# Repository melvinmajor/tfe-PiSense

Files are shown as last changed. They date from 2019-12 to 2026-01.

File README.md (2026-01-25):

> # PiSense
>
> *Originally: graduation work, 3rd Bachelor at EPHEC Louvain-la-Neuve*
>
> *Development pursued after the defense (project was well seen by the jury).*

PiSense logo

## The project

As part of a business request by Dreamnet SRL, an IoT system that tracks temperature, humidity and CO2 in a room is required to meet a future project to new needs.

Based on first feedback with Professor A. Dewulf (EPHEC), there is also interest in detecting Silicon Oxide from a client with a career.
This will allow the customer to prevent any risk related to the presence of Silicon Oxide at a rate too high.

> *The project is now functional under a [localhost web](localhost-web/) version with further options available on each sensors made compatible.*
>
> *If you want to use an external [web](web/) environment, please create your own API/database server with an online web environment.*
> *The Raspberry Pi code has a flag to fluently send collected data to an external environment.*

### Goal

Allow the optimization of the staff environment.
Studies have shown that a room with the right room temperature and good air quality can help focus and improve human health and productivity.

Multiple articles have been published, both from researchers and journalists based on the various studies carried out.
To cite only a few french sources, these two are explaining in summary the value of monitoring and optimizing the environmental data of the workplace:

* <https://www.francetvinfo.fr/replay-radio/c-est-mon-boulot/la-chaleur-a-des-effets-negatifs-sur-la-productivite_3486911.html>
* <https://www.forbes.fr/management/bonheur-au-travail-le-corps-ce-grand-oublie/>

In addition, it seems that in the professional environment, air pollution is an aggravating factor for respiratory pathologies.
An article correlate the facilitated spread of COVID-19 in this type of environment, was published by Le Soir and is available at the following address:

* <https://www.rtbf.be/info/societe/detail_le-coronavirus-pourrait-rester-plusieurs-heures-dans-l-air-a-cause-de-la-pollution-atmospherique?id=10464049>

In the case of the teacher's return, it would be a matter of warning of a possible danger in a risky work environment.

### Further research (after graduation defense)

After my graduation defense, I decided to pursue this project during my free time.
That's why I still make some commits 😉

By making further research, I learned that a desirable temperature is between 19 and 24°C (Canadian CSA Z412-17 Office Ergonomics suggest between 20 and 26°C).
The average humidity level is usually between 50 and 60% indoors even though between 40 and 70% there may not be high concerns.
Some articles and research published online explain this:

* <https://www.ccohs.ca/oshanswers/phys_agents/thermal_comfort.html>
* <http://ijesi.org/papers/Vol(4)3/Version-1/B043107014.pdf>
* <https://www.rubson.com/fr/a-propos-d-humidite/causes/niveau-parfait-humidite.html>

It seems that a bad humidity level can be linked to building and health aggravations.
For example:

* Humidity level below 20% can cause discomfort through dried eyes, mucous membranes and skin, skin and throat irritation.
It also causes static electricity build-up and negatively affect the operations of some office equipment such as printers and computers.
Apparently, it also has an impact on an easier drop in temperature which facilitates drying out the surrounding air.
* Humidity level above 70% may develop condensation on surfaces and within the interior of some equipment and building structures. If threatened, these areas can develop mould and fungi but also makes the area feel stuffy.
People with allergies may see their allergic reactions possibly worsening.

### Revival of the project (PiSense Lite, starting Q4 2024)

After taking a break from the project, I decided to work back on it with a lighter version, designed to be used in combination with a Home Assistant system.

If you are not aware, Home Assistant is an open source home automation system that puts local control and privacy first.
The project, from the Open Home Foundation, is stored on [GitHub](https://github.com/home-assistant) and their own [website](https://www.home-assistant.io/).

This revival, is stored under [PiSense-Lite with Home Assistant](PiSense-Lite%20with%20Home%20Assistant/) folder.

## License

This project is, by now on, protected under GNU General Public License v3.0 (see [LICENSE file](LICENSE)).
It's made available on GitHub for "documentation" purpose.

If you want to distribute it and/or use it commercially, please reach me before doing anything.
This condition is here since the very start of this repository project and is not meant to block the usage of my code.
It is only to be sure rights, patents and distribution are well respected based on me, the author.

## Built With and For

 

   

* [PyCharm Community Edition](https://www.jetbrains.com/pycharm/) - A great Python IDE

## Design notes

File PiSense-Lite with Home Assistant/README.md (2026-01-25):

> # PiSense Lite
>
> *Lite version of the project, with a focus on small energy consumption and compatibility with Home Assistant.*
> 
> Be aware this part of PiSense is purely for personal use. The code might need to be adapted for your needs.

PiSense logo

## The project

The project is to provide [Home Assistant](https://www.home-assistant.io/) with data from a sensor connected to a microcontroller.

In the case of this project, the microcontroller is a Raspberry Pi Pico W and the sensor selected is the Bosch BME680.
This sensor is interesting as it's a small and reliable one, giving measures of temperature, humidity, pressure and gas (which can be used to calculate VOC and AQI).
The Pico W is chosen as it has built-in WiFi capabilities, which will help us on requests between Home Assistant and the microcontroller.

The expected energy consumption should be around 50-60mA, making it quite energy efficient.

It is likely that other sensors will be added in the future, but the main priority is this first sensor.
Adapting the code for another microcontroller is possible (like an Arduino for example).

### Goal

* A fully working microcontroller with one or several sensors,
* An established communication between the microcontroller and Home Assistant via MQTT protocol,
* The integration of the sensors in a Home Assistant dashboard.

## Installation

For early adopters, feel free to follow this tutorial to connect your Raspberry Pi Pico to Arduino: <https://randomnerdtutorials.com/programming-raspberry-pi-pico-w-arduino-ide/>

In Arduino IDE, go into Preferences and enter the following URL into the "Additional Boards Manager URLs" field: <https://github.com/earlephilhower/arduino-pico/releases/download/global/package_rp2040_index.json>

You will also need to install couple modules in Arduino:

* Raspberry Pi Pico/RP2040
* WiFiManager
* PubSubClient

You will find in the Arduino file a bunch of variables at the beginning, feel free to adapt it to your needs:

```
// Replace with your WiFi credentials
const char* ssid = "YourSSID";
const char* password = "YourPassword";

// MQTT Broker
const char* mqtt_devicename = "PicoBME680"; // Name of the device in MQTT
const char* mqtt_server = "192.168.xxx.xxx"; // IP of the MQTT broker (Home Assistant)
const int mqtt_port = 1883; // Default port of Mosquitto MQTT is 1883. The secure one with SSL/TLS is 8883.
const char* mqtt_user = "mqttUserName";
const char* mqtt_password = "mqttPassword";
```
**Be sure you have MQTT installed on your Home Assistant as well as Mosquitto broker.**

In your Home Assistant, open the file editor and edit `configuration.yaml` to include the following:

```
mqtt:
  sensor:
    - name: "PiSense Temperature"
      state_topic: "home/pisense/bme680"
    - name: "PiSense Humidity"
      state_topic: "home/pisense/bme680"
    - name: "PiSense Pressure"
      state_topic: "home/pisense/bme680"
    - name: "PiSense Gas Resistance"
      state_topic: "home/pisense/bme680"
```

## License

This project is, by now on, protected under GNU General Public License v3.0 (see [LICENSE file](../LICENSE)).
It's made available on GitHub for "documentation" purpose.

If you want to distribute it and/or use it commercially, please reach me before doing anything.
This condition is here since the very start of this repository project and is not meant to block the usage of my code.
It is only to be sure rights, patents and distribution are well respected based on me, the author.

## Built With and For



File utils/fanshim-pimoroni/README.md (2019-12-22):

# Fan Shim for Raspberry Pi

> [Fanshim Python repository from Pimoroni](https://github.com/pimoroni/fanshim-python)

## Installing

* Stable library from PyPi: `sudo pip install fanshim`
* Latest/developement library from GitHub: `./fanshim-firstLaunch.sh` (fanshim pip will also be installed using this way)
  * If you have already installed it from GitHub and want to launch the app back: `./fanshim-launcher.sh`

As the code from Pimoroni install all the necessary things and create a service with our custom parameters implemented in the script, you won't need to relaunch the script at each reboot.

## Description

This part of the project will be used only when a fanshim must be set up on the device.

For example :

* Not really necessary for the Raspberry Pi Zero,
* Interesting for the Raspberry Pi 3 but not necessary,
* Highly recommended for the Raspberry Pi 4.

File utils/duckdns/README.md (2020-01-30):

# Duck DNS

Duck DNS is a free dynamic DNS hosted on AWS.
 
In fact, it helps to point a DNS (sub domains of [duckdns.org](https://www.duckdns.org/)) to an IP of your choice.

## Dynamic DNS service

It's a handy way to refer to a server/router with an easily rememberable name, where the servers IP address is likely to change.
When the router reconnects or ec2 server reboots, its IP address is set by the provider of that connection.
It means it may update at any time.

For the purpose of this project, the usage of Duck DNS is very handy as the Raspberry Pi is set on a DDNS environment.

## How to use

Simply run the script with the token set in argument: ´sudo ./duck.sh h3r3-1s-duckdns-t0k3n´.

It will return the token entered and then launch the process to connect to the Duck DNS service implemented.

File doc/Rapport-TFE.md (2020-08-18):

---
subtitle: Travail de fin d'études présenté en vue de l'obtention du diplôme de bachelier en Informatique et Systèmes orientation Technologie de l’informatique
date: Juin 2020
keywords: [TFE, graduation, work, PiSense, IoT, sensors, dev, report, TFE, graduation, rapport, EPHEC, 3TI]
header-left: Système modulable de prises de mesures environnementales avec affichage
footer-left: Rapport de TFE
footer-center: EPHEC 2019/2020
toc: true
toc-own-page: true
toc-title: Rapport de travail de fin d'études
---

# Système modulable de prises de mesures environnementales sur Raspberry Pi avec système d’affichage

> _**Titre du travail de fin d'études :**_ Système modulable de prises de mesures environnementales sur Raspberry Pi avec système d’affichage
>
> _**Nom temporaire prévu pour sa commercialisation :**_ PiSense
>
> _**Repository GitHub :**_ <https://github.com/melvinmajor/tfe-PiSense>
>
> _**Environnement web déployé :**_ <https://www.camposcasares.be>

**Préface**

Je souhaite tout d'abord remercier Dreamnet SRL et leurs contacts, car sans eux, ce projet n'aurait sans doute pas existé.
Leur soutien à été d'une grande aide malgré les circonstances atténuantes lié au COVID-19.

Je remercie également mon rapporteur de TFE, le professeur Arnaud Dewulf, pour les multiples échanges que nous avons eus et qui m'a permis de me conforter dans le choix de certains capteurs et de particularités à tenir en compte au niveau de l'aspect électronique de ce travail de fin d'études.

Je remercie également le client venant du professeur Arnaud Dewulf qui m'a orienté vers une réflexion poussée sur LoRaWAN et Zigbee.
Cela m'a permis de tenir en compte de possibles ouvertures en termes de moyen de communication.
De plus, il m'a permis de rediriger mes choix de capteurs afin de rendre ce travail le plus générique possible avec possibilité de personnalisation.
Malheureusement, au vu des circonstances mondiales rencontrées, nos échanges n'ont finalement pas donné de suite.

**Mesures liées au Coronavirus**

Suite aux mesures liées au Coronavirus, un impact non négligeable a eu lieu envers l'avancement du TFE.
En effet, il a été nécessaire de réadapter les échanges avec les deux clients et n'ai plus eu de retour concernant l'un d'eux.
De plus, avec les mesures gouvernementales prises et vivant seul, la distanciation sociale s'est faite ressentir de façon conséquente, impliquant une perte de motivation.
Quelques soucis de santé ont également été rencontrés durant cette période, faisant qu'un retard au niveau du développement de ce projet s'est installé ; retard dont j'ai mis un point d'honneur à récupérer.

En concertation avec le client principal, Dreamnet SRL, le développement s'est vu adapté.
L'optique principale étant d'avoir l'appareil de suivi environnemental opérationnel (pouvant communiquer avec une API et inscrire les données au sein d'une base de données), l'aspect web s'est vu altéré afin de montrer la possibilité de communication, sans pour autant avoir une gestion d'inscription et connexion utilisateur.

Vu les règles en vigueur lors du confinement, les colis jugés non prioritaires ont été retardés, occasionnant ainsi un retard considérable pour la réception du capteur SDS011 permettant la mesure de l'indice de qualité de l'air.

\pagebreak

## Introduction

Nous vivons dans un monde en perpétuelle évolution où la technologie prend une place d’importance majeure.
Les appareils connectés passent peu à peu d’une idée de conception à un produit se trouvant dans chaque foyer.
Malheureusement, il est rare de trouver à l’heure actuelle une solution tout-en-un permettant de suivre les informations environnementales directement depuis une interface web simple et efficace.

Dans un désir de suivre les informations environnementales de mon espace de vie, j'ai pris contact avec plusieurs entreprises, afin de voir le potentiel derrière ce projet.

Suite à des échanges avec plusieurs clients potentiels, ce travail de fin d’études s’est peu à peu dessiné.
Une entreprise mettait en avant l’intérêt d’obtenir des données liées à la température, l’humidité et la qualité de l’air afin d’améliorer la productivité de leurs employés.
Une autre mettait en avant la nécessité de suivre l’évolution de la présence d’un gaz spécifique dans un lieu donné, afin de prévenir d’un danger pouvant s’avérer mortel.

**En combinant les besoins et intérêts, les prémices de ce travail sont nées et de nouvelles questions venaient en tête :**

* _Serait-il possible d’imaginer une solution de petite taille et répondant aux demandes ?_
* _Est-ce que cette solution peut être générique afin d’être ouvert a tous ?_

De plus, avec les récents évènements liés au COVID-19, une réflexion approfondie a été réalisée concernant la mesure de la qualité de l’air suite à la publication de recherches spécifiques au coronavirus.

Vous découvrirez dans ce rapport la façon dont ce travail a été développé ainsi que certaines analyses réalisées.

### Analyse du projet

Un schéma d'analyse et un schéma du réseau physique ont été réalisés afin d'offrir une vue d'ensemble rapide sur la solution mise en place.

Vous les découvrirez aux pages suivantes.

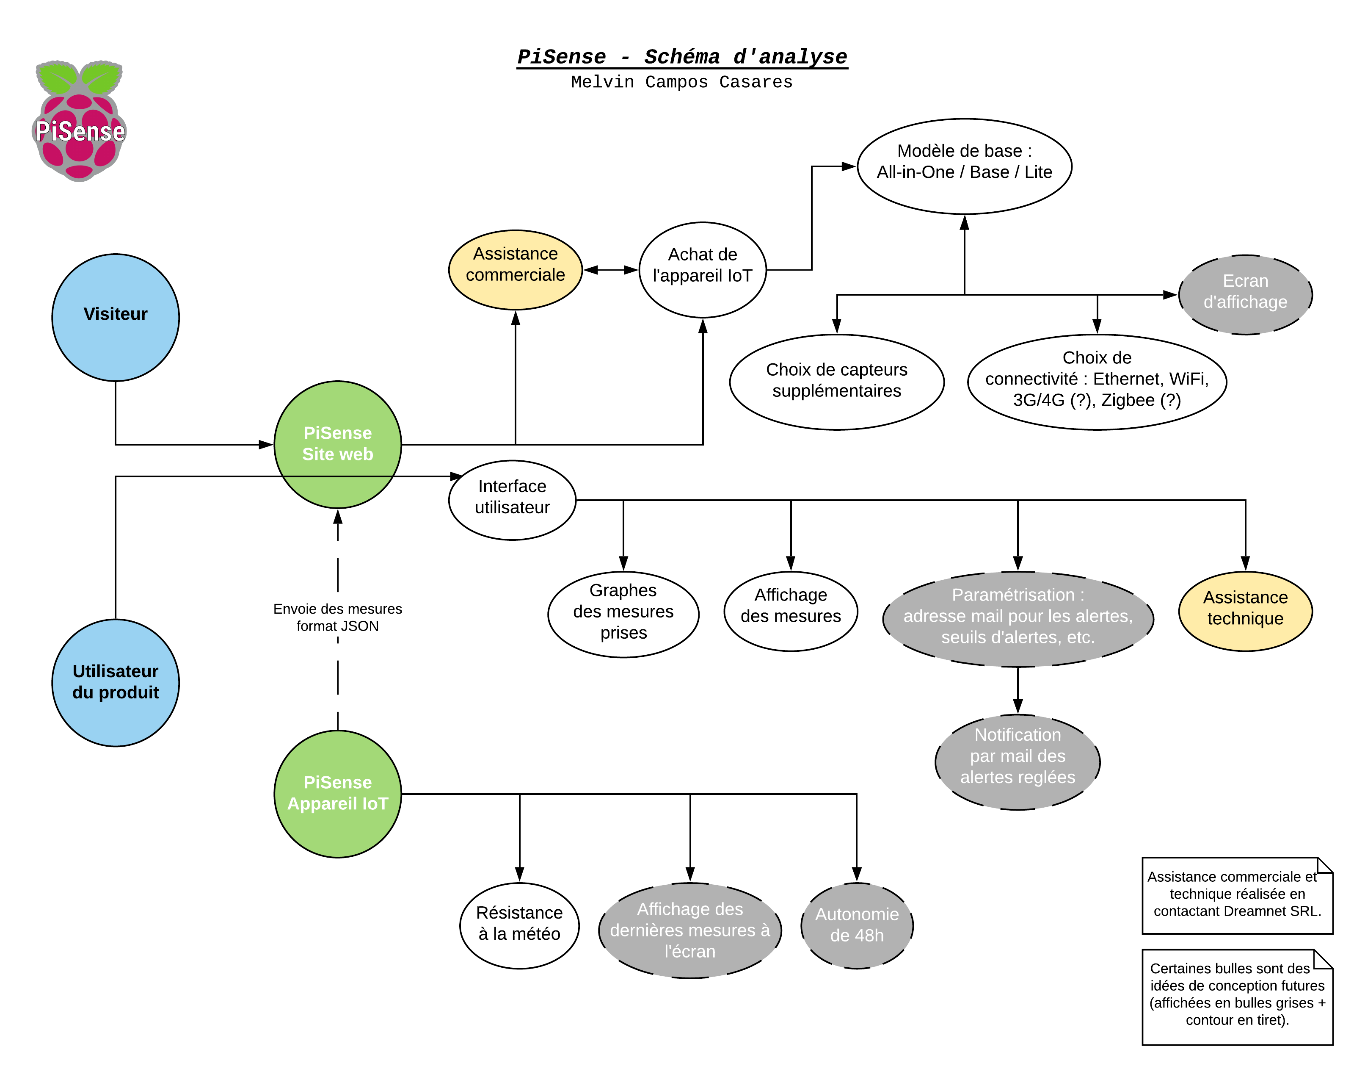
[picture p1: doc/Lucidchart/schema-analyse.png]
Schéma d'analyse du TFE


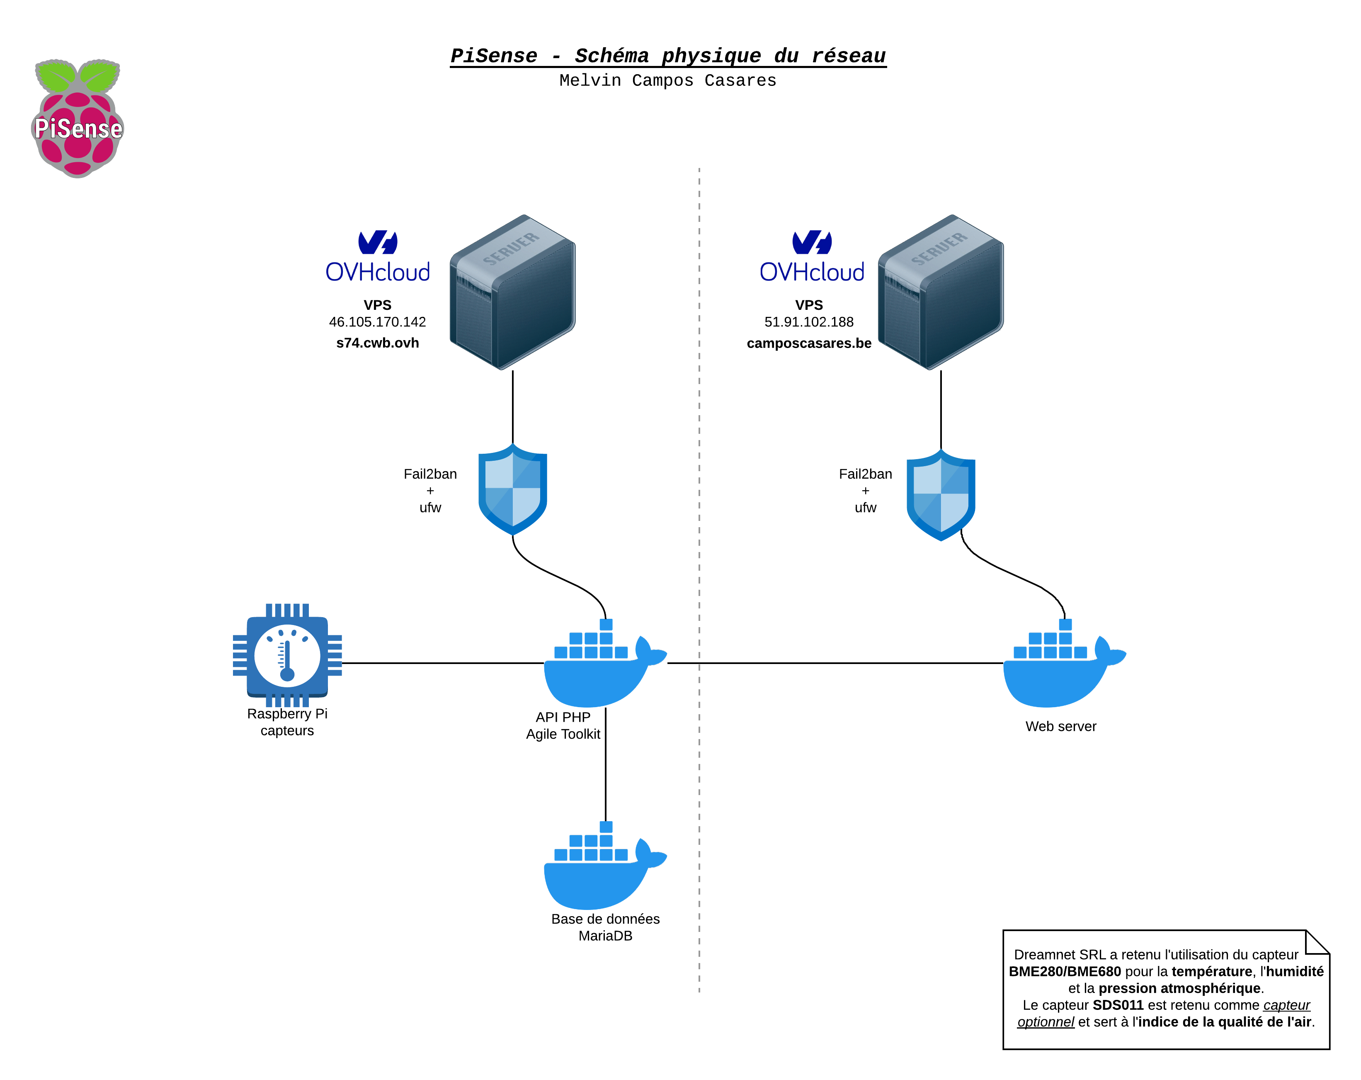
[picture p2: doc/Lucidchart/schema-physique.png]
Schéma physique du réseau


\pagebreak

## Informations générales de ce projet

### Contexte et présentation

Dans le cadre d’une requête professionnelle demandée par la société Dreamnet SRL, un système IoT permettant le suivi de la température, de l’humidité et du taux de CO2 au sein d’une pièce est requis afin de répondre à un projet futur faisant face à de nouveaux besoins.

Sur base de premiers retours avec le professeur A. Dewulf, un intérêt est également présent pour détecter de l’Oxyde de Silicium auprès d’un client disposant d’une carrière.
Cela permettra au client de prévenir de tous risques lié à une présence de l’Oxyde de Silicium à un taux trop élevé.

### But

Permettre l’optimisation de l’environnement du personnel.
Des études ont prouvé qu’une pièce à bonne température ambiante et avec une qualité d’air adéquate permet d’aider à la concentration et à améliorer l’état de santé ainsi que la productivité de l’être humain.

De multiples articles ont été publiés, tant venant de chercheurs que de journalistes se basant sur les différentes études réalisées.
Pour ne citer que quelques sources, en voici deux expliquant de façon synthétique l'intérêt de suivre les données environnementales du lieu de travail et de l'optimiser :

* <https://www.francetvinfo.fr/replay-radio/c-est-mon-boulot/la-chaleur-a-des-effets-negatifs-sur-la-productivite_3486911.html>
* <https://www.forbes.fr/management/bonheur-au-travail-le-corps-ce-grand-oublie/>

De plus, il semblerait que dans le milieu professionnel, la pollution atmosphérique est un facteur aggravant pour les pathologies respiratoires.
Un article allant dans ce sens, mettant en corrélation la propagation facilitée du COVID-19 dans ce type d'environnement, a été publié par Le Soir et est disponible à l'adresse suivante :

* <https://www.rtbf.be/info/societe/detail_le-coronavirus-pourrait-rester-plusieurs-heures-dans-l-air-a-cause-de-la-pollution-atmospherique?id=10464049>

Dans le cas des retours du professeur, il s’agirait de prévenir d’un éventuel danger dans un milieu de travail à risque.

### Besoins et contraintes

Il est demandé de mettre en place une solution IoT munie de capteurs « à la carte » ainsi que de différents moyens de communication au choix pour l’utilisateur final.

Ce choix permettra au client de définir ce dont il a besoin : Wi-Fi ou Ethernet.

Un moyen d’accès aisé aux informations est à mettre en place.
Le prix d’achat des composants pour créer l’appareil doit être le moins coûteux possible.
De ce fait, une analyse des différents composants disponibles sur le marché et de leur précision a été réalisée lors de l'élaboration du cahier de charges et de l'analyse technique afin de retenir uniquement les composants ayant un bon rapport précision/prix.

Concernant les nécessités du client disposant d’une carrière, une solution entièrement sans fil est à envisager.
L’utilisation d’une batterie d’une certaine capacité pourrait s’avérer pratique à moins que le client dispose d’une prise 220V non loin de la zone où il souhaite mettre en place l’appareil.

Malheureusement, au vu des problèmes rencontrés liés au confinement, les échanges avec le 2ème client n'ont plus eu lieu.

Étant donné que l’appareil pourrait être mis en extérieur, un boîtier étanche est à étudier.

#### Contraintes

* L’appareil IoT doit rester relativement petit (de taille « acceptable »),
* L’appareil IoT et les capteurs doivent être à un prix correct (volonté de ne pas dépasser les 500 € pour le kit complet avec tous les moyens de communication éventuellement intégrés),
* La possibilité à un développeur tiers d’accéder aux données de l’appareil via une API ou un environnement Cloud (non obligatoire, mais souhaité),
* La possibilité d’une solution entièrement sans fil,
* Résistance aux intempéries si l’appareil est mis en extérieur (résistance à la pluie).

\pagebreak

## Analyse de sécurité

En termes de sécurité, il va de soi que l'environnement web doit être sécurisé par un certificat SSL et une protection liée aux données des utilisateurs.
Dreamnet SRL conseille l'utilisation du certificat Let's Encrypt, étant un certificat gratuit et renouvelé de façon régulière.
L'augmentation de la sécurité par le biais de _Security Headers_ à implémenter sur la plateforme web est également une méthode intéressante à inclure.

> Concernant la sécurité mise en place sur la plateforme web, les éléments mis en place sont expliqués dans le point consacré à cet effet dans la section _Développement du projet > Site internet > Sécurité_.

Le moyen de communication de la Raspberry doit être le plus générique possible afin que même si une personne externe vient à récolter les informations, aucune information personnelle liée à l'utilisateur ne puisse être récupérée à son insu.

\pagebreak

## Développement du projet

### Méthodologie

Des réunions régulières ont été prévues avec Dreamnet SRL afin de s'assurer que la direction suivie soit la bonne.
La méthodologie suivie s'apparente donc aux méthodologies Agile et plus précisément Scrum.

Avec la période compliquée que nous avons subi, certaines contraintes ont été rencontrées, forçant de changer la manière de s'organiser ainsi que de la mise en place des réunions.

Le développement à débuté sur la partie IoT avec la Raspberry Pi pour ensuite laisser place au développement d'un site internet _"maquette"_.

### Raspberry Pi

Le développement a débuté avec la Raspberry Pi.
Plusieurs éléments ont été développés :

* Système de connexion à distance sécurisée par interface graphique via VNC Viewer (Raspberry Pi servant de serveur),
* Protection à la connexion par interface console par protocole SSH,
* Intégration d'un service permettant l'allongement de la durée de vie de la carte microSD,
* Développement d'un service permettant le refroidissement du processeur de la Raspberry Pi 4 via un ventilateur connecté sur le module GPIO intégré (la Raspberry Pi 4 est réputée pour avoir un processeur qui chauffe),
* Développement des différents capteurs.

Concernant les capteurs, tout a été développé avec le langage de programmation Python, l'intégration d'un service de logs avec rotation et suppression automatique de l'historique ancien de plus de 30 jours.

#### Capteurs

La réception des capteurs s'étant faite en plusieurs parties (3 fournisseurs différents pour 4 capteurs), 3 des 4 capteurs ont été reçus avant le confinement.
Le dernier capteur, le SDS011 permettant la mesure de l'indice de la qualité de l'air par le biais des normes PM2.5 et PM10, a été livré pratiquement 2 mois après avoir effectué la commande.

Voici les différents capteurs commandés et intégrés dans ce projet (ils sont tous fonctionnels) :

* _**Bosch BMP280**_ (modèle basé sur la librairie Adafruit) : prise de mesures de la température et humidité.
* _**Bosch BME280**_ (modèle basé sur la librairie Adafruit) : prise de mesures de la température, humidité et pression atmosphérique.
* _**Bosch BME680**_ (modèle de Pimoroni) : prise de mesures de la température, humidité, pression atmosphérique et calcul des taux de CO2 et composés organiques volatils totaux.
* _**Nova SDS011**_ : prise de mesures de l'air par le biais d'un laser et détection des particules fines d'après les normes de diamètre aérodynamique PM2.5 (< 2,5 µm) et PM10 (< 10 µm).

> À titre de comparaison, le diamètre aérodynamique d'un cheveu humain est de 50 à 70 µm.

En effet, mise à part le capteur BME680 en provenance du Royaume-Uni et commandé directement auprès de Pimoroni, les autres capteurs étaient tous en provenance de Chine.
Adafruit proposait de les commander directement de chez eux, mais le coût étant relativement conséquent, j'ai jugé bon de réduire les frais du TFE et commander les premiers capteurs dès la confirmation du sujet de TFE.

#### Journalisation d'événements, menu d'aide du script, etc.

En termes de dépassement, l'implémentation d'un système de rotation des fichiers "logs" propre à la Raspberry Pi avec suppression automatisée des fichiers datant de plus de 30 jours a été mise en place.
Toutes les informations jugées pertinentes _(données formatées en JSON et prêt pour l'envoi vers l'API, réponse de réussite ou d'erreur lors de l'envoi vers l'API, etc.)_ sont stockées dans un fichier de journalisation d'événements ayant la dénomination suivante : `NomDuCapteur.log.Année-Mois-Jour` _(exemple : bme680.log.2020-06-01)_.

De plus, un menu d'aide a été intégré pour chacun des capteurs permettant de démarrer le script avec la déclaration personnalisée de l'URL du serveur API, du temps entre chaque prise de mesures et la version du script présent sur l'appareil.

_**Voici le menu d'aide du capteur BME280 :**_

`mcc@RasbperryPi4: $ sudo python3 bme280/bme280sensor.py --help`

```fish
usage: PiSense BME280 [-h] [-u URL] [-t TIME] [-v]

BME280 module sensor of PiSense

optional arguments:
  -h, --help            show this help message and exit
  -u URL, --url URL     URL of the API
  -t TIME, --time TIME  Time, in seconds, between each record taken
  -v, --version         PiSense BME280 program version
```

#### Photos de l'appareil

Voici, aux pages suivantes, des photos de la Raspberry Pi 4 dans un boitier en aluminium, sous différents angles et avec les capteurs branché.

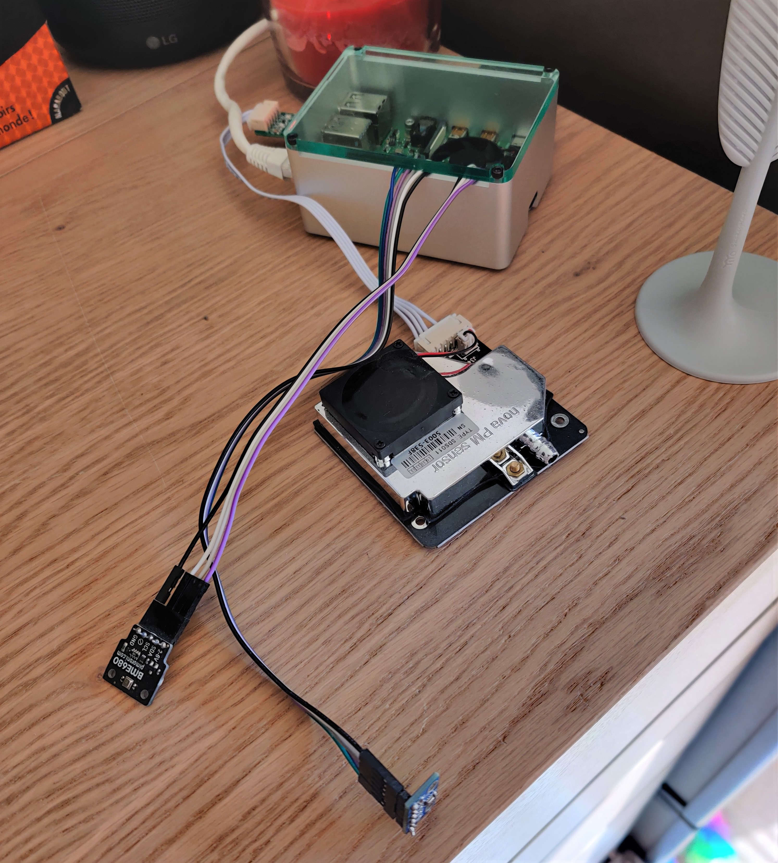
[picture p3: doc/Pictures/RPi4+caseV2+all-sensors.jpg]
Raspberry Pi 4 avec les capteurs BME280, BME680 et SDS011 branché


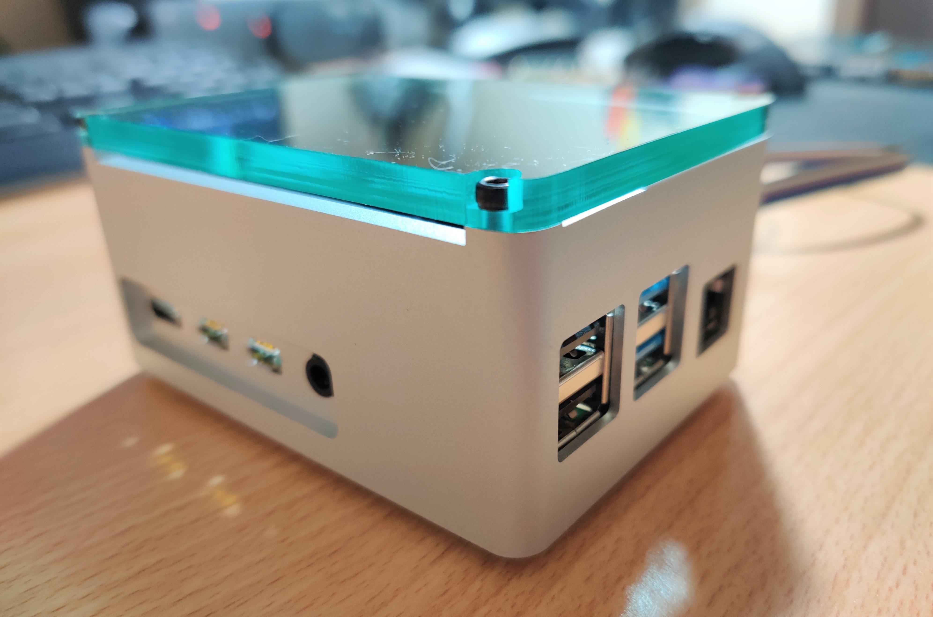
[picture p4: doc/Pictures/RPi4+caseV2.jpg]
Raspberry Pi 4 avec un boitier en aluminium


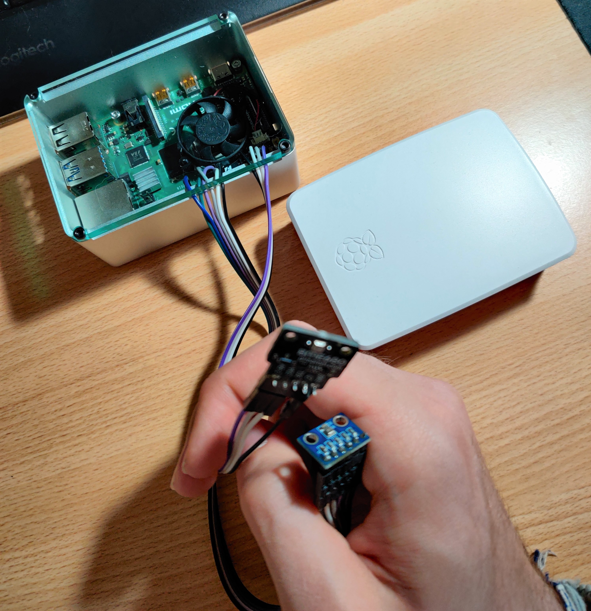
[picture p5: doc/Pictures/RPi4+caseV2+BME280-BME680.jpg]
Raspberry Pi 4, vu de haut, avec les capteurs BME280 et BME680 branché


\pagebreak

### Site internet

Au niveau du site internet, il était originellement prévu de travailler sur une plateforme avec le framework React.JS.
J'ai rapidement pu remarquer les limites de cet environnement de développement par rapport aux besoins de ce projet et aie donc entrepris de changer d'environnement de travail.

#### Sécurité

##### Certificat Let's Encrypt (HTTPS)

Concernant la sécurité, le certificat HTTPS a été mis en place.
Let's Encrypt a été utilisé, avec `certbot` afin d'automatiser son renouvellement.

Let's Encrypt est une autorité de certification gratuite, automatisée et ouverte, exploitée pour le bénéfice du public. C'est un service fourni par l’Internet Security Research Group (ISRG).
Leur optique étant de créer un Web plus sûr et respectueux de la vie privée, ils offrent les certificats numériques pour activer le protocole de sécurité HTTPS (SSL/TLS) pour les sites web, gratuitement.

On peut remarquer sa mise en place sur le serveur web via le rapport de sécurité réalisé auprès de Qualys :

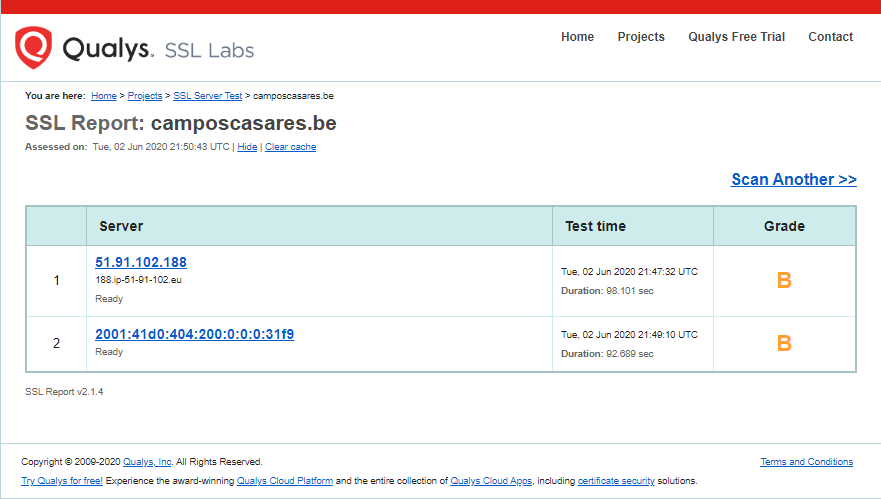
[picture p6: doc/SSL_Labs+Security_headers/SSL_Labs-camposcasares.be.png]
Rapport de sécurité SSL


##### En-tête de sécurité

De plus, des security headers ont été mis en place afin d'assurer une protection supplémentaire de la plateforme web.
En protégeant les en-têtes de sécurité HTTP/HTTPS, les attaques et les vulnérabilités de sécurité sont atténuées.

Les en-têtes de sécurité HTTP sont la réponse au navigateur, lorsqu'il effectue une requête.
Certains de ces en-têtes contiennent de méta data de contenu tels que le code de statut, la méthode utilisée par la requête (GET/POST...), l'adresse URL de la requête, le contenu d'encodage et le contrôle de la cache.
Cela définit donc notamment comment le navigateur web doit réagir en affichant le contenu de la page web demandée.

Voici le rapport d'analyse des en-têtes de sécurité de la plateforme :

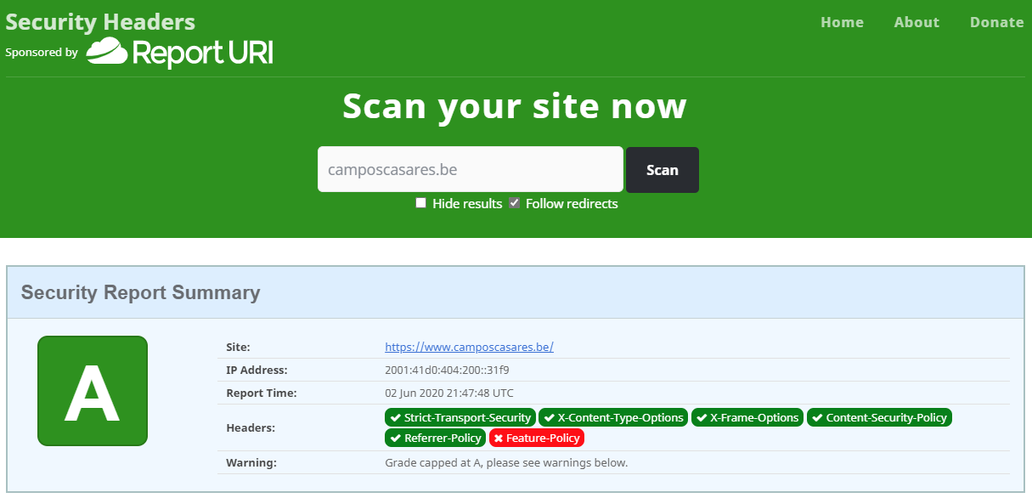
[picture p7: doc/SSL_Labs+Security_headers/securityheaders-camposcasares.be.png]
Rapport des security headers


###### Content Security Policy (CSP)

Cette stratégie permet de prévenir des attaques, telles que le script de site croisé (XSS) et d'autres attaques d'injection de code en définissant les sources de contenu approuvées et en permettant au navigateur de les charger.

Dans la configuration du serveur NGINX, cela concerne : `Content-Security-Policy`.

###### Filtre de script de site croisé (X XSS-Protection)

L’en-tête est conçu pour activer le filtre de script de site croisé (XSS) intégré dans les navigateurs web modernes.
Il est généralement activé par défaut, mais le spécifier est toujours préférable.

Dans la configuration du serveur NGINX, cela concerne : `add_header X-XSS-Protection "1; mode=block" always;`

###### HTTP Transport de sécurité stricte (HSTS)

Il permet de restreindre les navigateurs web pour accéder au serveur web uniquement via le protocole de sécurité HTTPS.
Cela garantit que la connexion ne peut pas être établie via une connexion HTTP non sécurisée et ainsi prévenir de susceptibles attaques.

Dans la configuration du serveur NGINX, cela concerne : `Strict-Transport-Security`.

###### Protection de clics

En utilisant `X-Frame-Options`, une protection contre les clics est établie et les iframes ne peuvent pas être chargées sur le site web.

###### Blocage de détection de réponse éloignée

`X-Content-Type-Options` permet de prévenir la détection de réponse éloignée déclarée.
Cela permet de réduire le risque de téléchargements de type "drive-by" (= téléchargement de contenu autorisé sans tenir compte des conséquences (exécutable contrefait, application non reconnue/signée...)) et ainsi traiter le contenu de la bonne façon.

###### Référence de politique HTTP

`Referrer-Policy` contrôle la quantité d'informations de référence, qui doit être incluse dans les demandes.

Sur le serveur NGINX, `strict-origin-when-cross-origin` a été défini.
Concrètement, l'origine est envoyée (le chemin et la chaîne de requête) lors de l'exécution d'une demande de même origine.
L'origine n'est envoyée que lorsque le niveau de sécurité du protocole reste le même lors de l'exécution d'une demande d'origine croisée (HTTPS → HTTPS), et n'envoie aucun en-tête à un système moins sécurisé (HTTPS → HTTP).

#### Changement du serveur web vers Python Flask

Fin mars, j'ai entrepris la conversion complète du site internet pour travailler sur le framework Flask prévu pour Python.

Afin d'améliorer au maximum le rendement de ce framework, le modèle MVT a été suivi (ce modèle est expliqué à la suite dans un point dédié).
L'avantage de Python Flask est son intégration plus aisée de l'API ainsi que de la base de données.

Afin de comprendre au mieux l'utilisation de Flask, j'ai suivi la formation en ligne "Concevez un site avec Flask" sur OpenClassrooms.

##### Modèle MVT

Concernant la plateforme web, le modèle MVT (Modèle - Vue - Template) est suivi.

* Le modèle est la structure de l'objet dans la base de données.
  Concrètement, il est représenté par le fichier `models.py`.
* La vue décide du contenu qui sera affiché sur une page ; c'est elle qui génère le contenu à renvoyer aux requêtes adressées.
  Concrètement, il est représenté par le fichier `views.py`.
* Le template est un fichier HTML recevant des objets Python et lié à une vue.
  Concrètement, il est représenté par le dossier `templates` et tout fichier présent dans ce dernier.

##### API

Python Flask permet la mise en place d'une API (Application Programming Interface).
La documentation fournie sur le site internet officiel de Flask est relativement complète.

Dans le cadre de ce projet, j'ai suivi la formation en ligne "Adoptez les API REST pour vos projets web" sur OpenClassrooms.
Cette formation m'a permis de mieux visualiser les concepts théoriques derrière les API et ainsi orienter la programmation de ce dernier.

###### Changement de l'API vers PHP Agile Toolkit framework

Malheureusement, en avançant dans la construction de l'API, j'ai été face à quelques problèmes de compréhension afin de mettre en place correctement les éléments nécessaires pour finaliser le site web avec Python Flask.
Arrivé début mai, j'ai dès lors pris contact avec Dreamnet SRL afin de changer un peu les attentes du projet et convenir d'un arrangement.

Une partie du cahier de charges original concernant le site web est donc reléguée à un développement ultérieur, la partie échange de communication entre la Raspberry Pi et le site web étant la priorité.

Le langage final choisi est PHP avec Agile Toolkit et la conversion entre ce qui a déjà été réalisé sous Python Flask et le nouvel environnement sous PHP n'a pas occasionné un retard plus conséquent que celui déjà préexistant.

#### Impression d'écran de l'interface web

Voici l'interface utilisateur disponible en ligne.
Il présente de façon claire et détaillée les mesures prises des 30 derniers jours.
L'utilisateur peut parcourir avec sa souris les mesures prises à chaque instant s'il souhaite plus de détails.

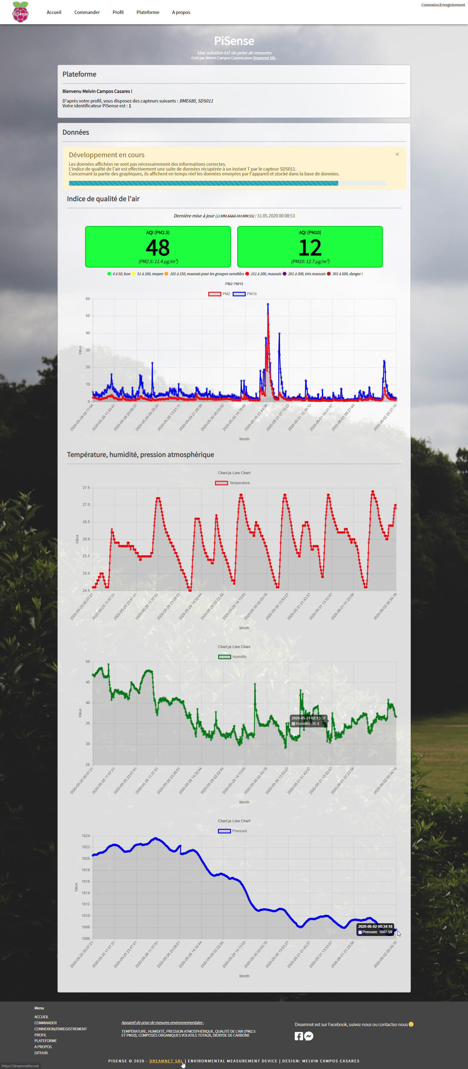
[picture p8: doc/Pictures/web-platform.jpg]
Impression d'écran de l'interface web avec les graphes


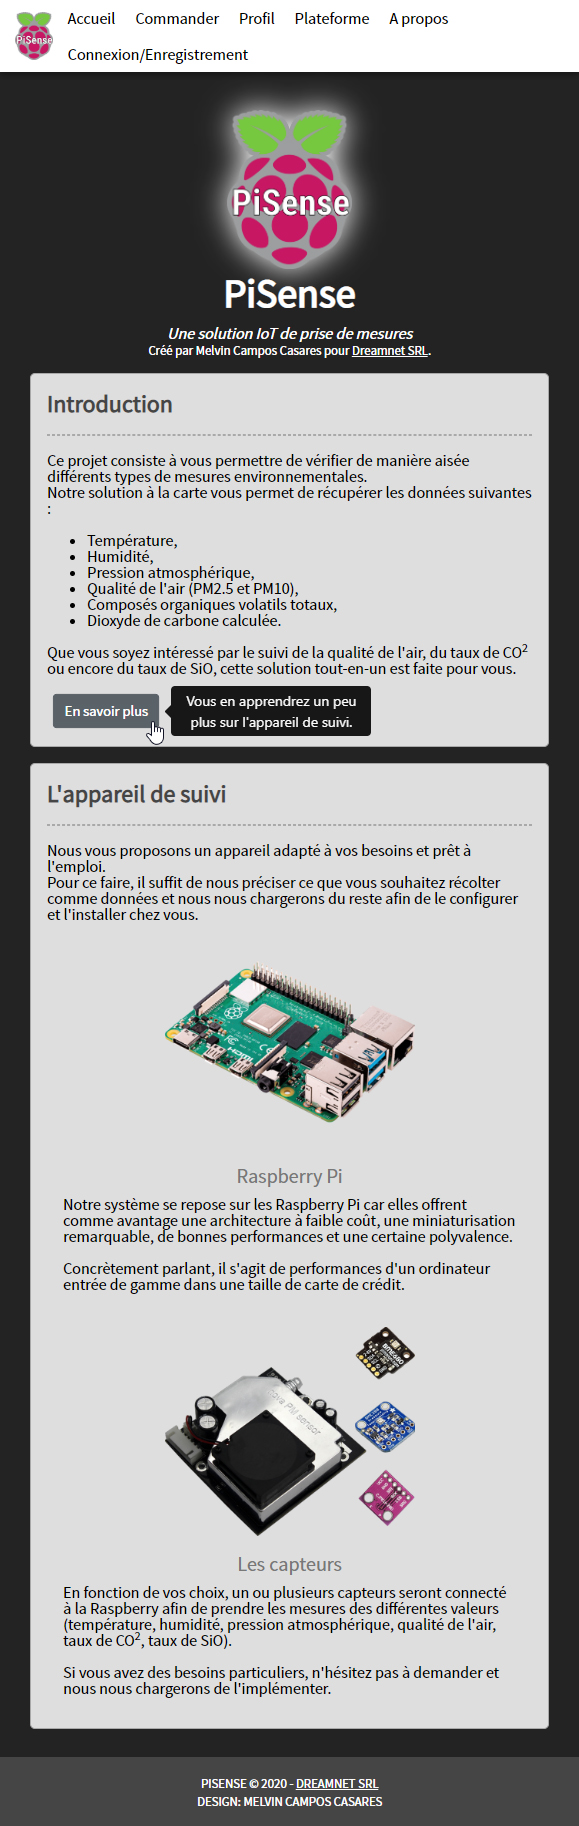
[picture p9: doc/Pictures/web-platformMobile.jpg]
Impression d'écran de la page d'accueil sur un appareil mobile


\pagebreak

### Base de données

Lors du choix de technologies, il était décidé de partir sur MariaDB, car jugé plus intéressant en termes de fonctionnalités, stabilité et de la licence Open SQL Server en comparaison de MySQL.
Au vu de certaines incompatibilités rencontrées avec MariaDB lors de l'implémentation de l'environnement web sous Python Flask, SQLite a été le choix de prototypage retenu, mais MariaDB est bel et bien la solution retenue et déployée grâce au changement de structure utilisée lors de la mise en place de l'API.

Concrètement parlant, la base de données comporte 2 tables :

* _**User**_ :
  Elle contient toutes les informations liées à l'utilisateur. Nous y trouverons son nom et prénom, adresse e-mail, mot de passe (qui sera protégé), date d'inscription et s'il est en possession d'un appareil de suivi ainsi que de quel(s) capteur(s).
* _**Box**_ :
  Elle contient les informations liées à la Raspberry Pi et les capteurs. Nous y trouverons les différentes informations environnementales tout comme l'ID de l'appareil ainsi que l'horodatage de la prise de mesure.

> À noter que la présence des données des capteurs dans la table Box est un choix réfléchi et à pour but de simplifier les requêtes réalisées auprès de l'API et la base de données afin de rendre l'inscription et la récupération des informations plus rapide et efficace.

Avec les changements occasionnés au niveau du site internet ainsi que les réadaptations nécessaires au niveau du développement dû aux circonstances liées au COVID-19, seule la table Box sera utilisée même si la table User est fonctionnelle et utilisable pour le développement ultérieur par le client.

\pagebreak

## Problèmes rencontrés

### Confinement (COVID-19)

Avec cette période exceptionnelle que nous rencontrons cette année via la présence de mesures strictes de confinement afin de contrer le coronavirus, cela a eu un impact non négligeable sur l'avancée de ce TFE.

En effet, avec le stage en télétravail, les quelques semaines de stage suspendus qui sont à rattraper et la distanciation sociale, j'ai dû réadapter à plusieurs reprises mon planning de travail.
Vivant seul, j'ai ressenti la distanciation sociale de façon conséquente et ait perdu mon rythme de travail, entre autres, dû à un manque de motivation lié à la solitude ressentie et quelques soucis de santé rencontrée.

De plus, je n'ai eu que peu d'échanges avec les clients concernant mon TFE faisant que le développement n'a pu être avancé principalement que sur base des notes prises lors d'entrevues avant les mesures prises par le gouvernement.
Dreamnet SRL a répondu présent lors de nos échanges par mail malgré une réponse parfois lente dû à une surcharge de travail lié aux urgences clientèle, mais je n'ai eu aucune nouvelle du second client.

Au vu des règles en vigueur lors du confinement, les colis jugés non prioritaires se sont vu être retardés, occasionnant ainsi un retard considérable pour la réception du capteur SDS011 permettant la mesure de l'indice de qualité de l'air.

### Incompatibilité entre les technologies choisies

Au début du projet, sur base des demandes du client et d'une analyse amenant à l'élaboration d'un cahier de charges, certains choix de technologies m'avaient semblé évidents.
C'était sans compter la complexité de mise en place du framework React.JS au niveau de l'environnement web.

Une première réadaptation des choix technologiques a été faite en quittant le framework React.JS au profit du framework Flask.

Malheureusement, des soucis de connexion entre Python Flask et la base de données MariaDB se sont présentés très rapidement, nécessitant le changement vers SQLite qui lui, ne pose aucun problème d'interaction par le biais du module SQLAlchemy utilisé par Flask pour interagir avec une base de données.

Au vu de la réadaptation du développement de l'API, SQLite s'est avéré être efficace lors du prototypage, mais MariaDB a finalement été mis en place avec l'API PHP sous framework Agile Toolkit, respectant ainsi l'intérêt premier au niveau du choix technologique de la base de données.

\pagebreak

## Piste d'amélioration

### Mise en place d'un système de connexion utilisateur

Comme prévu pour la version commercialisable de ce sujet de TFE, un environnement permettant aux utilisateurs de s'inscrire et avoir accès aux informations spécifiques de leur compte pourrait être mis en place.

Cela permettrait ainsi de profiter d'un environnement unique et facile d'utilisation pour l'utilisateur sans la nécessité de dépendre d'un site internet unique à chacun.

### Application permettant la configuration rapide de la Raspberry Pi

Une application mobile se connectant à la Raspberry Pi pourrait être développée afin de faciliter la première mise en route.
De cette manière, l'utilisateur n'aurait plus à devoir fournir les informations de connexion à son réseau sans fil et pourrait de lui-même configurer et reconfigurer à souhait son appareil de suivi de mesures.

### Système de commande complète en ligne

À l'heure actuelle, la prise en charge des commandes se réalise exclusivement que par prise de contact via échange mail et/ou par appel téléphonique avec Dreamnet SRL.
Un formulaire pourrait être mis en place avec système de processus de paiement par carte bancaire afin d'automatiser la commande.

### Utilisation de la modélisation 3D d'un boitier adapté au projet

Une modélisation 3D d'un boitier permettant l'installation d'une Raspberry Pi avec le capteur Nova SDS011 ainsi qu'un second capteur au choix parmi BMP280/BME280/BME680 a été réalisé.

Théoriquement, les mesures devraient être correctes et la modélisation utilisable pour sa production.
Néanmoins, il serait intéressant de vérifier cela en pratique, réaliser les modifications éventuelles à apporter et ainsi profiter d'une solution entièrement personnalisée pour sa commercialisation.

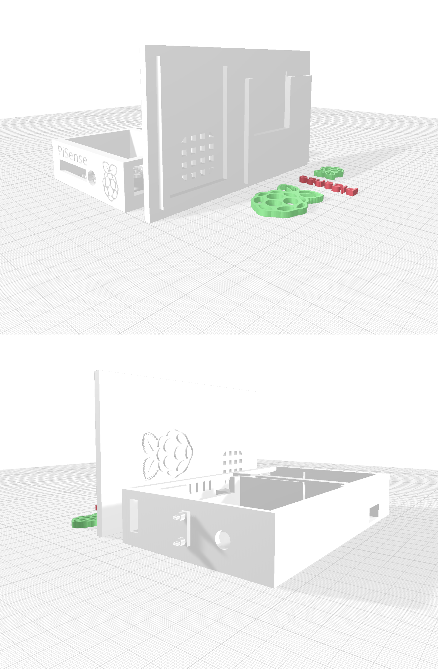
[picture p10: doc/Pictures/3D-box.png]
Modélisation 3D d'un boitier prévu pour l'appareil de prises de mesures envrionnementales


\pagebreak

## Conclusion

Ce sujet de TFE m'a énormément appris.
J'ai eu l'occasion de pouvoir m'améliorer dans le langage de programmation Python, mieux comprendre certaines utilisations au niveau des modules et librairies, mais également de comprendre les différences entre Python 2.x et Python 3.x.
En effet, parmi les différents capteurs utilisés dans le cadre de ce projet, le capteur de détection de fines particules ne disposant pas de librairies spécifique et ayant une communication en série, il ne m'était pas possible de travailler avec ce capteur en Python 3.x tout comme les autres capteurs.

Certains choix technologiques décidés au départ lors de l'écriture du cahier de charges se sont avérés rendre le travail complexe et lors de l'avancement du développement, je me suis rapidement rendu compte des incompatibilités sur certains aspects.
Cela a occasionné un retard qui était nécessaire à rattraper pour mener à bien ce projet.

La situation particulière que nous avons vécue en ce début d'année 2020, avec la présence du confinement lié à la pandémie du COVID-19, a rendu difficile l'avancement du travail de fin d'études comme expliqué précédemment dans les problèmes rencontrés.

Le cahier de charges a dû être revu avec le client afin de rester réalisable et s'assurer des bons choix technologiques.
La communication avec les clients s'est avérée être plus difficile durant cette période de pandémie, mais des arrangements ont pu être trouvés afin de pouvoir discuter du projet sans être livré intégralement à soi.

En termes de développement, la partie concernant l'appareil de suivi environnemental est intégralement fonctionnelle.
L'API et la base de données sont également fonctionnels et l'appareil de suivi interagit sans problème avec.
L'environnement web présente les possibilités d'interaction utilisateur envisageable (visibilité des graphes), mais aucune gestion de notification sur base d'alertes personnalisées ou de création de compte utilisateur/connexion utilisateur n'est gérée malgré que la structure soit existante au niveau de l'API et de la base de données, comme convenu avec le client.

\pagebreak

## Bibliographie

_**Partie IoT/Raspberry Pi :**_

* _Raspberry Pi 4 GPIO Pinout_, par Eduardo Pecina, <https://maker.pro/raspberry-pi/tutorial/raspberry-pi-4-gpio-pinout>
* _Adafruit BME280 Humidity + Barometric Pressure + Temperature Sensor Breakout_, <https://learn.adafruit.com/adafruit-bme280-humidity-barometric-pressure-temperature-sensor-breakout>
* _Adafruit BMP280 library_, repository GitHub appartenant à Adafruit, <https://github.com/adafruit/Adafruit_BMP280_Library>
* _Adafruit BME280 library_, repository GitHub appartenant à Adafruit, <https://github.com/adafruit/Adafruit_BME280_Library>
* _Pimoroni BME680 library_, repository GitHub appartenant à Pimoroni, <https://github.com/pimoroni/bme680>
* _Getting Started with BME680 Breakout_, Pimoroni, <https://learn.pimoroni.com/tutorial/sandyj/getting-started-with-bme680-breakout>
* _SDS011 dust sensor reading_, code publié sur GitHub appartenant à kadamski, <https://gist.github.com/kadamski/92653913a53baf9dd1a8>
* _Fanshim Python_, repository GitHub appartenant à Pimoroni, <https://github.com/pimoroni/fanshim-python>
* _Apprenez à programmer en Python_, Openclassrooms, <https://openclassrooms.com/fr/courses/235344-apprenez-a-programmer-en-python>
* _Getting Started with Fan SHIM_, PIMORONI, <https://learn.pimoroni.com/tutorial/sandyj/getting-started-with-fan-shim>
* _Requests : HTTP for Humans_, <https://requests.readthedocs.io/en/master/>
* _Python’s Requests Library (Guide)_, publié le 23/01/2019, <https://realpython.com/python-requests/>
* _Documentation Python v3.7_, Python Software Foundation, <https://docs.python.org/3.7/>
* _Python 3 - JSON encoder and decoder_, Python Software Foundation, <https://docs.python.org/3/library/json.html>

_**Partie web :**_

* _Documentation Python v3.7_, Python Software Foundation, <https://docs.python.org/3.7/>
* _Flask Documentation_, <https://flask.palletsprojects.com/en/1.1.x/>
* _Flask API documentation_, <https://flask.palletsprojects.com/en/1.1.x/api/>
* _Documentation Bootstrap_, Bootstrap, <https://getbootstrap.com/docs/4.5/getting-started/introduction/>
* _Code Snipetts | CSS-Tricks_, CSS-tricks, <https://css-tricks.com/snippets/>
* _CSS Almanac | CSS-Tricks_, CSS-tricks, <https://css-tricks.com/almanac/>
* _ChartJS_, ChartJS, <https://www.chartjs.org/>
* _Agile Toolkit_, <https://agiletoolkit.org/>
* _Agile UI Documentation_, <https://agile-ui.readthedocs.io/en/latest/>

_**Partie Base de données :**_

* _Documentation MariaDB_, <https://mariadb.com/kb/en/documentation/>
* _Documentation SQLite_, <https://sqlite.org/docs.html>

_**Partie API :**_

* _Adoptez les API REST pour vos projets web_, Openclassrooms, <https://openclassrooms.com/fr/courses/6573181-adoptez-les-api-rest-pour-vos-projets-web>
* _ChartJS_, ChartJS, <https://www.chartjs.org/>
* _Agile Toolkit_, <https://agiletoolkit.org/>
* _Agile UI Documentation_, <https://agile-ui.readthedocs.io/en/latest/>
* _ATK Data - Data Access Framework for high-latency databases (Cloud SQL/NoSQL)_, repoistory GitHub appartenant à ATK4, <https://github.com/atk4/data/>

_**Autres sources :**_

* _docker-compose_, Docker, <https://docs.docker.com/compose/>
* _Use volumes_, Docker, <https://docs.docker.com/storage/volumes/>
* _Content Security Policy (CSP) Quick Reference Guide_, Foundeo Inc., <https://content-security-policy.com/>
* _La chaleur a des effets négatifs sur la productivité_, France TV Info, <https://www.francetvinfo.fr/replay-radio/c-est-mon-boulot/la-chaleur-a-des-effets-negatifs-sur-la-productivite_3486911.html>
* _Le bonheur au travail : le corps, ce grand oublié_, Forbes, <https://www.forbes.fr/management/bonheur-au-travail-le-corps-ce-grand-oublie/>
* _Pollution et propagation fulgurante du coronavirus, les particules fines montrées du doigt_, Le Soir, <https://www.rtbf.be/info/societe/detail_le-coronavirus-pourrait-rester-plusieurs-heures-dans-l-air-a-cause-de-la-pollution-atmospherique?id=10464049>

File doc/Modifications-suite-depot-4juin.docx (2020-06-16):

TFE - Résumé des modifications

- Gestion des erreurs 403 (accès refusé) et 405 (méthode/requête non autorisée ou n’aboutissant pas).
- Ajout d’une balise permettant la personnalisation de la couleur de la barre d’adresse dans les navigateurs compatibles (exemple : Google Chrome Mobile).
- Correction du message d’erreur à la connexion et correction de la redirection à la connexion.
- Ajout de balises « meta tags » : description, auteur, mots clés, robots (indexation et/ou suivi des pages web ou non).
- Écriture d’un mode d’emploi concernant la connexion des différents capteurs sur la Raspberry Pi (déjà présent dans le Wiki du repository GitHub).
- Préchargement HTTP Strict Transport Security (HSTS) : permet de s’assurer que les navigateurs gardent en mémoire le site internet comme étant certifié HTTPS.
- Amélioration des protocoles SSL et changement de grade d’après le rapport généré par Qualys SSL Labs : passage du grade B au grade A+.
- Test de rapidité effectué auprès de Testmysite.io (Netlify Speedtest) concernant le site internet : résultat de 86/100 obtenu, TTFB (Time To First Byte) pose problème comme la plupart des sites internet.

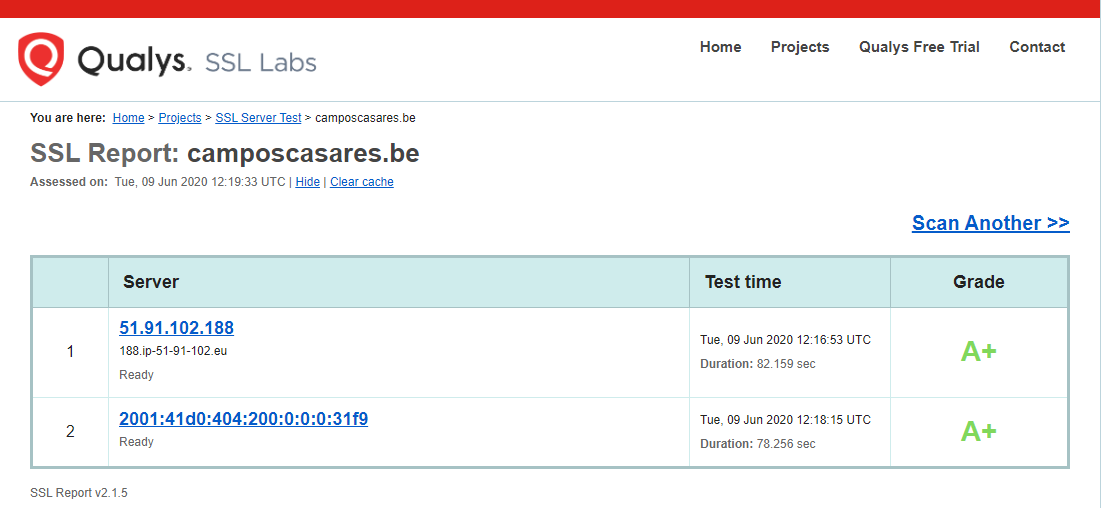
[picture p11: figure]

- Ajout du header Feature-Policy permettant la (dés)activation de certaines options des navigateurs et API pour une meilleure sécurité et respect de la vie privée.

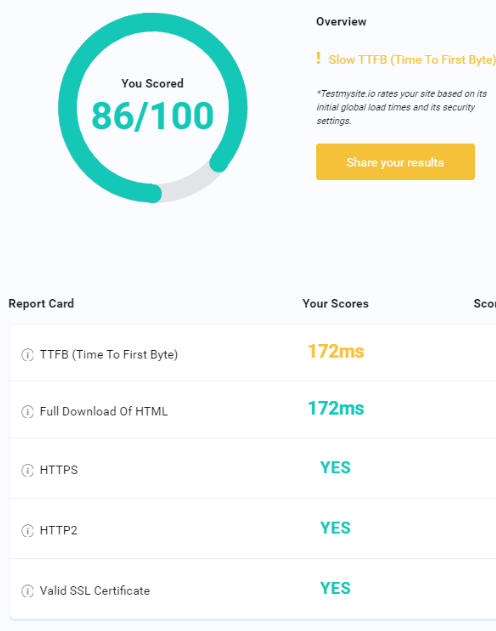
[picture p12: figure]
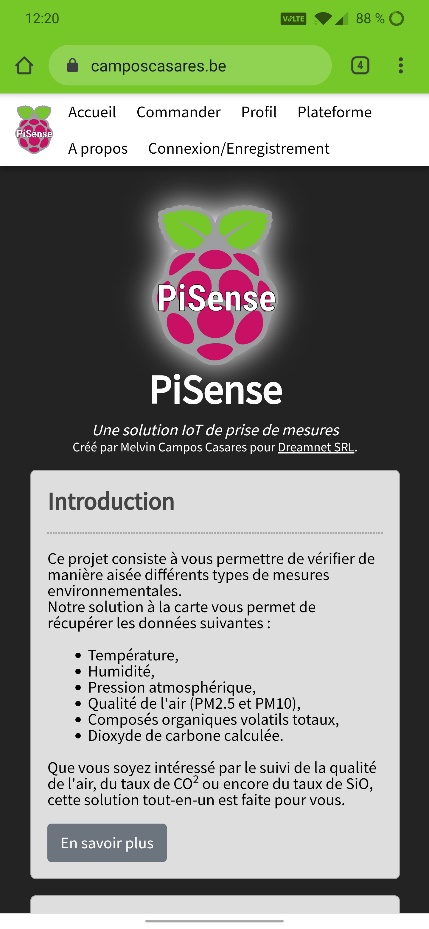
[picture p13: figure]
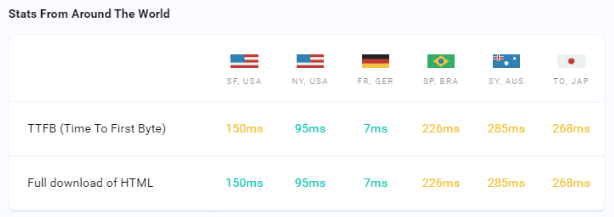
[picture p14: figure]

TFE : Système modulable de prises de mesures environnementales avec affichage Résumé des modifications suite au dépôt du 4 Juin 2020

Melvin Campos Casares EPHEC – 2019/2020 Rapporteur : Arnaud Dewulf Juin 2020

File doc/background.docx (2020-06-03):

3TL2

ECOLE PRATIQUE DES HAUTES ETUDES COMMERCIALES
EPHEC
Avenue du Ciseau, 15
1348 Louvain-la-Neuve

Année académique 2019-2020

EPHEC

Rapporteur : Arnaud Dewulf

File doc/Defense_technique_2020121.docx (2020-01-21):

Plan de présentation :

- Présentation du sujet de TFE
  - Titre : Plateforme web visant à afficher les mesures prises par une Raspberry Pi avec différents capteurs environnementaux et de gaz.
  - Quoi : Plateforme web reliée à un appareil de prise de mesures qui récupère différentes valeurs. Cet appareil est proposé à la carte (base générique) : température, humidité, pression atmosphérique, eCO2, COVT (= qualité de l’air).
  - Problématique :
    - Récolter des informations afin d’optimiser l’environnement du personnel et améliorer l’état de santé ainsi que la productivité de l’être humain,
    - Alerter en cas d’un éventuel danger dans un milieu de travail à risque.
  - Comment : J’ai eu cette idée peu avant le début de l’année académique en cours et j’ai soumis cette idée à une entreprise, Dreamnet SPRL, qui y voit un certain intérêt. Le professeur A. Dewulf a également un client potentiellement intéressé et qui aurait besoin d’un capteur détectant l’Oxyde de Silicium.
- Méthodologie et analyse
  - Méthodologie : Utilisation de l’outil de versioning Git hébergé sur GitHub. Utilisation de cartes et planning pour mieux cibler le développement. Utilisation de l’environnement Docker pour le déploiement des services web.
  - Technologies :
    - Site web : HTML/CSS/JS + librairie React
    - Serveur web : NGINX
    - IoT (Raspberry + les capteurs) : Python
    - API : type REST ? (échange de données en format JSON)
    - DB
  - Analyse : Aucun capteur disponible ne mesurant uniquement que l’Oxyde de Silicium, que des capteurs analysant la qualité de l’air par le biais des fines particules (PM2.5/PM10 – PMx désigne les particules dont le diamètre est inférieur à x micromètres). L’API est nécessaire parce que React ne peut pas se connecter à une base de données directement. L’API interagit avec la DB tout comme JS (pour demander les mesures à afficher sur le site). L’IoT interagit avec l’API pour envoyer les mesures à stocker dans la DB. NGINX choisi comme webserver pour sa rapidité et l’intérêt derrière sa configuration détaillée et le Reverse Proxy (permets la relation entre plusieurs serveurs). Commencement du développement de la partie IoT avant d’entamer la partie services web en parallèle et terminer par le site web.
- État d’avancement (voir page 3 pour plus de détails)
  - Analyse technique réalisée afin de mieux visualiser la plupart des contraintes à rencontrer,
  - 3 des 4 capteurs reçus et soudés (+ testé), attente du capteur SiO,
  - Modèle de ce à quoi ressemblerait potentiellement l’accueil du site réalisé,
  - Code Python d’un capteur déjà entamé.

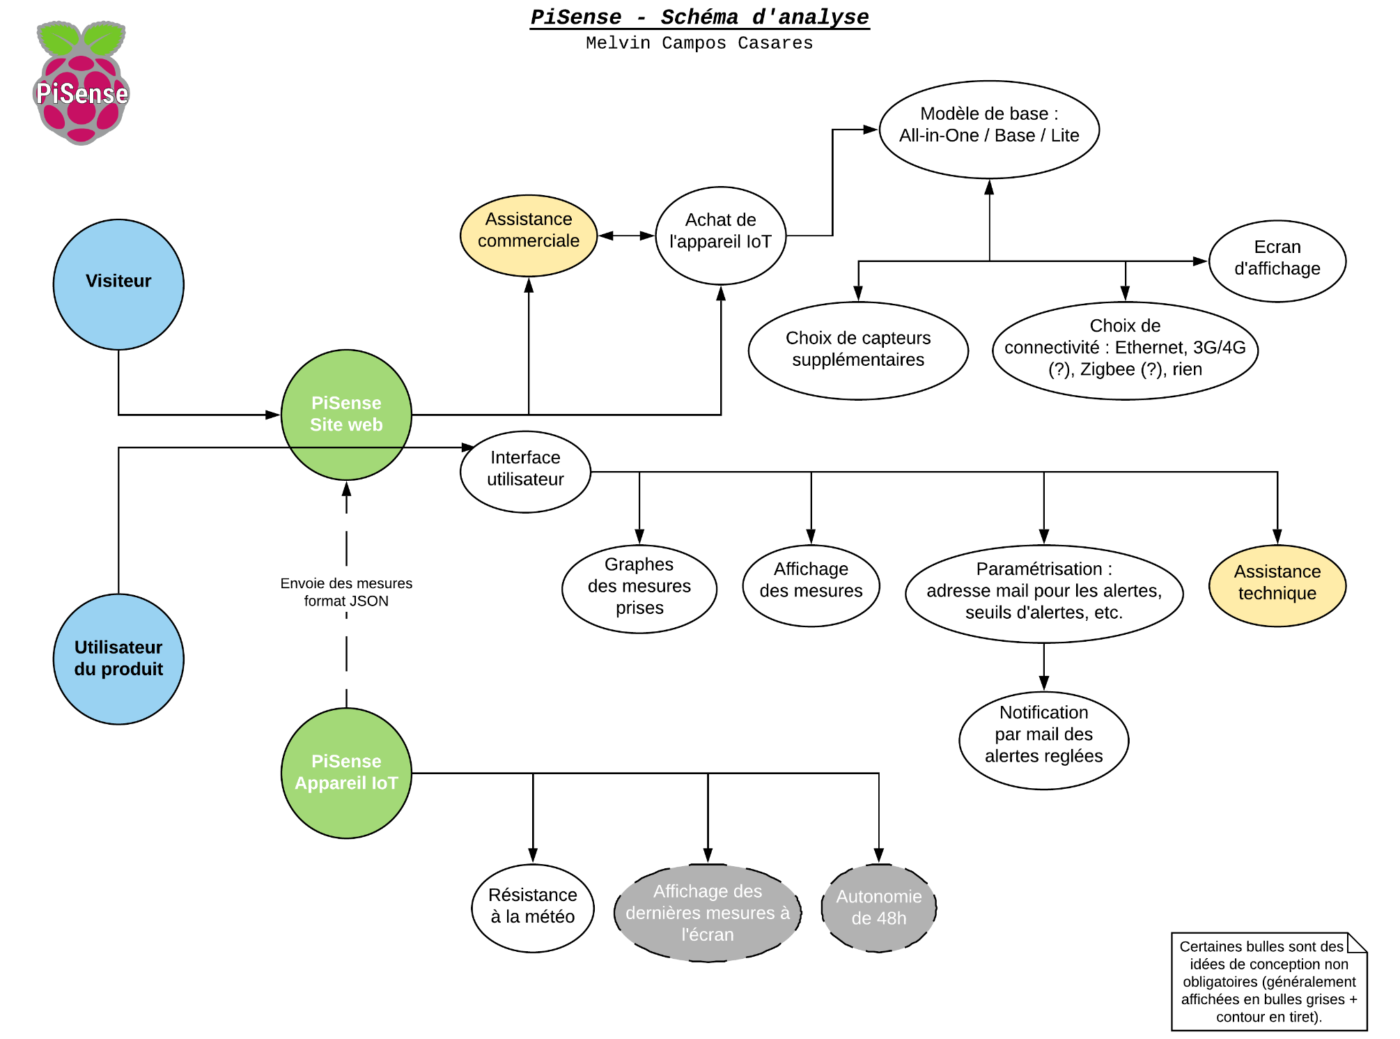
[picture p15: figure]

Repository GitHub : https://github.com/melvinmajor/tfe-PiSense

État d’avancement :

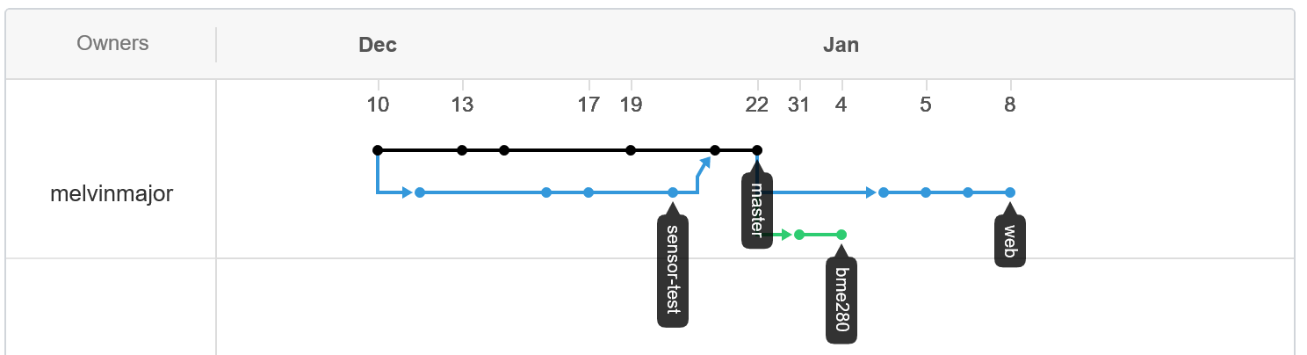
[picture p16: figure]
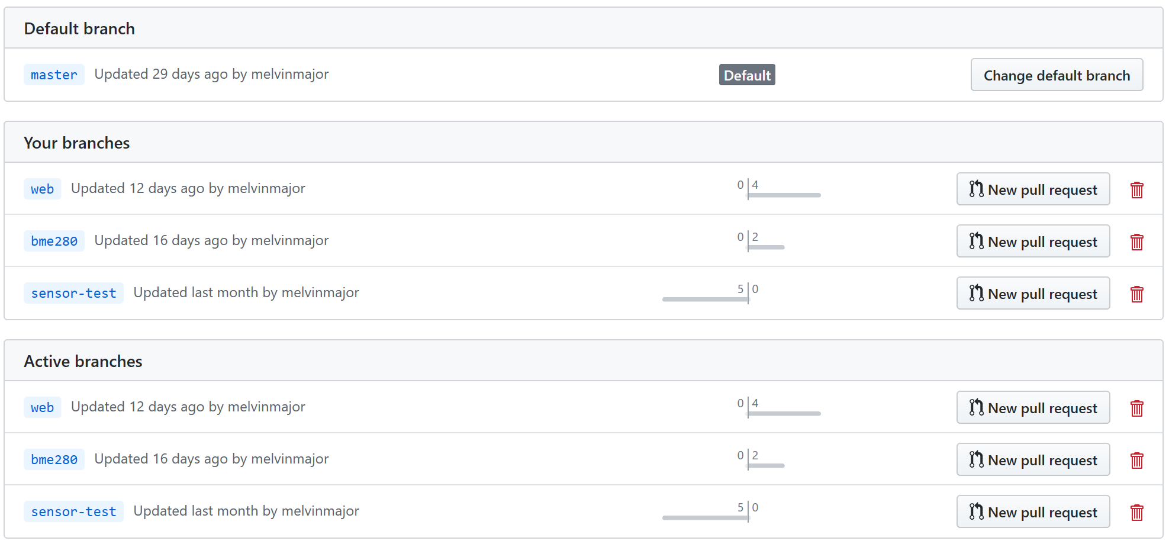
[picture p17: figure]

☒ Recherche des capteurs intéressants pour le sujet de TFE

☒ Cahier de charges

☒ Analyse technique

☒ Apprentissage de Python : cours sur OpenClassrooms

☒ Recherche des capteurs intéressants pour le sujet de TFE

☒ Réception et soudures sur les premiers capteurs retenus (3/4 achevé)

☒ Début du développement du code Python des capteurs

☒ Maquette de la page d’accueil du site internet

☐ Apprentissage de React.JS : cours sur OpenClassrooms

☐ Apprentissage de REST : cours sur OpenClassrooms

☐ Commande OVH : VPS et nom de domaine

☐ Configuration du VPS et du DNS

☐ Mise en place du webserver NGINX

☐ Début du développement de l’API et de la base de données

☐ Intégration de diverses méthodes de connexion de l’appareil IoT : 3G/4G, etc.

☒ Début du développement du site web
(pour l’instant que la page d’accueil en HTML/CSS afin de correspondre à la maquette)

☐ Site web responsive

☐ Phase de test dans divers environnements

Page 2 sur 2

Melvin Campos Casares 21/01/2020 - EPHEC 2019-2020 Travail de fin d’études Rapporteur de TFE : Professeur A. DEWULF

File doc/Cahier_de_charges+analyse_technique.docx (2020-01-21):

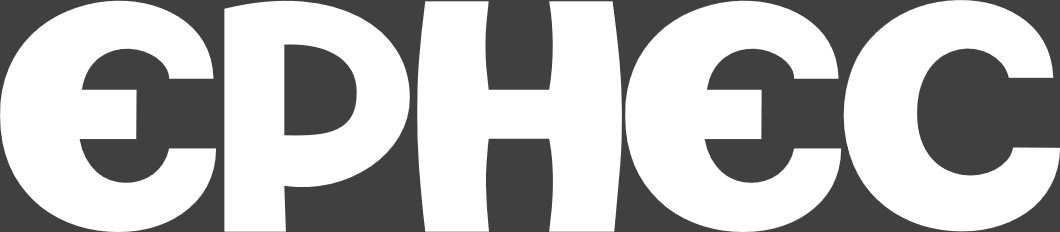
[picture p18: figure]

2019 2020

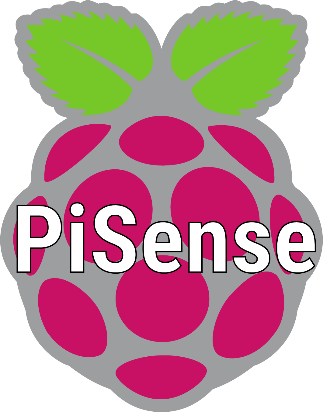
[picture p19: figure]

Travail de fin d’études
Cahier des charges et analyse technique

Solution IoT : PiSense

Melvin Campos Casares

PiSense

# Cahier des charges

## Contexte et présentation du projet

Dans le cadre d’une demande professionnelle demandée par la société Dreamnet SPRL, un système IoT permettant le suivi de la température, de l’humidité et du taux de CO2 au sein d’une pièce est requis afin de répondre à un projet futur répondant à de nouveaux besoins.

Sur base de premiers retours avec le professeur A. Dewulf, un intérêt est également présent pour détecter de l’Oxyde de Silicium auprès d’un client disposant d’une carrière. Cela permettra au client de prévenir de tout risque lié à une présence de l’Oxyde de Silicium à un taux trop élevé.

## But du projet

Permettre l’optimisation de l’environnement du personnel. Des études ont prouvé qu’une pièce à bonne température ambiante et avec une bonne qualité d’air permet d’aider à la concentration et améliorer l’état de santé ainsi que la productivité de l’être humain.

Dans le cas des retours du professeur, il s’agirait de prévenir d’un éventuel danger dans un milieu de travail à risque.

## Besoins et contraintes liés au projet

Concrètement parlant, il est demandé de mettre en place une solution IoT munie de capteurs « à la carte » ainsi que de différents moyens de communication au choix pour l’utilisateur final.
Ce choix permettra au client de définir ce dont il a besoin :

- Wi-Fi,
- Ethernet,
- Autres (écran en cas de demande de non-connectivité ? Zigbee ?).

Un moyen d’accès aisé aux informations est à mettre en place comme, par exemple, un système permettant d’afficher les informations actuelles (écran directement connecté au boitier, application mobile, site internet, etc. ?).
Le prix d’achat des composants pour créer l’appareil doit être le moins coûteux possible. De ce fait, une analyse des différents composants disponible sur le marché et de leur précision doit être réalisée afin de retenir uniquement que les composants ayant un bon rapport précision/prix.

Concernant les nécessités du client disposant d’une carrière, une solution entièrement sans fil est à envisager. L’utilisation d’une batterie d’une certaine capacité pourrait s’avérer pratique à moins que le client dispose d’une prise 220V non loin de la zone où il souhaite mettre en place l’appareil.
Ce point sera à développer lors d’une rencontre.

Étant donné que l’appareil pourrait être mis en extérieur, un boîtier étanche est à étudier.

Contraintes :

- L’appareil IoT doit rester relativement petit (de taille « acceptable »),
- L’appareil IoT et les capteurs doivent être à un prix correct (volonté de ne pas dépasser les 500€ pour le kit complet avec tous les moyens de communication éventuellement intégrés),
- La possibilité à un développeur tiers d’accéder aux données de l’appareil via une API ou un environnement Cloud (non obligatoire, mais souhaité),
- La possibilité d’une solution entièrement sans fil et disposant d’une autonomie d’au moins 48h,
- Résistance aux intempéries si l’appareil est mis en extérieur (résistance à la pluie).

## Coûts

Le premier client, Dreamnet SPRL, demande un détail concernant les coûts afin d’analyser et réfléchir à son éventuelle commercialisation.

Ce travail de fin d’études sera réalisé sur le dernier modèle de Raspberry, la Pi 4 modèle B.
Nous choisirons le modèle disposant de 2GB de mémoire vive tout en profitant du nouveau processeur Quad-Core 1.5GHz bien plus performant afin d’assurer une certaine stabilité lors des phases de débogages et de tests.

Bien entendu, ce projet sera supposé fonctionner, qu’importe la Raspberry choisie (Pi Zero, Pi 3 B+, Pi 4, etc.).

Cet aspect ne concerne pas les articles supplémentaires nécessaires pour l’installation du système d’exploitation et des accès (câble HDMI et adaptateur nécessaire).

Composant | Fournisseur | Prix | Délai de livraison
Raspberry Pi 4 modèle B (2GB) | Kubii | 48,96 € | 5 jours ouvrables
microSD SanDisk 64GB Classe 10 | Kubii | 18,95 € | 5 jours ouvrables
Ventilateur SHIM | Kubii | 7,95 € | 5 jours ouvrables
Heat sink Pi 4 + kit alu | Kubii | 3,45 € + 2,36 € | 5 jours ouvrables
Alimentation USB-C 15.3W | Kubii | 8,52 € | 5 jours ouvrables
Kit fils premium jumper 40x75mm F/F + M/F + M/M | Amazon | 6,59 € | Amazon Prime
Kit de tubes d’isolation | Amazon | 2,90 € | Amazon Prime
Capteur BME280 | Banggood UK | 6,32 € | 7 à 10 jours ouvrables
Capteur BME680 | Pimoroni | 18,60 £ | 5 à 7 jours ouvrables
Extension 11mm de connecteur GPIO | Pimoroni | 2,10 £ | 5 à 7 jours ouvrables
Adafruit FT232H Breakout (USB to GPIO+SPI+I2C) | Pimoroni | 13,80 £ | 5 à 7 jours ouvrables
Capteur laser Nova PM2.5 SDS011 | AliExpress | 15,77 € | 1 mois ouvrable
Câble RJ45 CAT6 3m | Amazon | 5,49 € | Amazon Prime
ELEGOO kit 6x170 points breadboard | Amazon | 12,99 € | Amazon Prime
10m câble en cuivre | Banggood CN | 4,58 € | 6 à 14 jours ouvrables
GPIO carte de référence | Banggood CN | 3,14 € | 6 à 14 jours ouvrables
Kit cylindres hexagonaux en laiton | Banggood CN | 2,39 € | 6 à 14 jours ouvrables
PiZiGate | ZiGate | 29,- € | ?
Antenne externe | ZiGate | 9,- € | ?

Au choix ventilateur SHIM ou dissipateur de chaleur passif. Pour Raspberry Pi 4, vivement conseillé d’utiliser le ventilateur.

Coût total | Frais de livraison | Fournisseur
90,19 € | Gratuit à partir de 100,- € - 7,90 € sinon | Kubii
6,32 € | 1,81 € + assurance 0,13 € | Banggood UK
34,50 £ | 5,- £ | Pimoroni
15,77 € | 1,16 € | AliExpress
10,11 € | 2,38 € | Banggood CN
27,97 € | Livraison offerte Prime | Amazon
38,- € | 9,- € | ZiGate

Le coût total des composants, frais de port et assurance inclus, s’élève à : 210,74 € + 39,50 £
Sans compter une éventuelle batterie, le boitier, un affichage, etc.

Un boitier coûterait 17,99 € (si boitier de dérivation de Brico, taille 220x170x85mm, IP65*).
* IP65 : totalement protégé contre les poussières, protégé contre les jets d’eau de toutes les directions à la lance (buse de 6,3mm, distance 2,5-3m, débit 12,5l/min ± 5%).

## Résultats attendus

Le client attend une solution tout-en-un prête à l’emploi, fourni avec un mode d’emploi et un document explicatif de mise en marche lors de sa première utilisation.

Il doit pouvoir voir les données actuellement récoltées par les différents capteurs.

Le rapporteur demande à penser à interagir aisément avec l’appareil que ce soit via une application mobile ou un site web (une des deux solutions, libre de choix).

Dreamnet SPRL se réserve le droit de proposer l’appareil à la vente sur le marché.
Cela ne les dérange pas que le client disposant d’une carrière puisse en profiter via ce travail de fin d’études et non à l’achat directement auprès d’eux.

Le client disposant d’une carrière à émis son intérêt quant à l’utilisation d’un moyen de communication avec Internet par d’autres moyens que le réseau mobile (3G/4G) ou Wi-Fi/Ethernet dû à un manque crucial de couverture. Il a émis l’intérêt pour Zigbee et dispose de bonnes connaissances pour cette technologie.
Dès lors, on suppose qu’il attend en résultat la possibilité d’utiliser un moyen de communication différent de ceux plus conventionnels, même si plus coûteux, si la mise en place d’une application mobile ou d’un site web se concrétise.
Il est envisagé de lui proposer un affichage au cas où le système de communication ne saurait pas être établi dû à un manque de couverture réseau.

# Technique

## Concept

Le concept ici serait de partir des demandes de l’entreprise et de l’étendre afin d’avoir un produit plus générique pouvant répondre à différents besoins.

Par conséquent, un capteur « solution tout-en-un » basé sur des composants de marque Bosch réputée pour un superbe rapport qualité/prix et leur fiabilité accrue est retenu.

Ces capteurs (BMP280, BME280, BME680) permettront de mesurer la température, le taux d’humidité, la pression atmosphérique barométrique et la qualité de l’air. Étant donné la fiabilité des capteurs, ils pourraient servir d’altimètre quoique, peu conseillé au vu des premiers tests réalisés par moi-même.

L’avantage est qu’avec l’unique capteur BME680, nous pouvons en plus détecter le taux de dioxyde de carbone calculé (eCO2) ainsi que la concentration en composés organiques volatils (COVT).
Pour la première détection (eCO2), cela permettrait de prévenir la nécessité d’aérer la pièce.
Pour la seconde détection (COVT), nous pourrions prévenir d’un dépassement d’un gaz quelconque et ainsi alerter les employés d’évacuer les locaux dans les plus brefs délais.

Cela signifie que cette solution IoT pourrait servir de station météo, de système de vérification de la qualité de l’air et température ou même de prévenir d’un danger lié à un gaz nocif pour la santé.

Ce système pourrait être proposé en 3 versions :

- PiSense All-in-One (BME680)
- PiSense Base (BME280 avec/sans capteur de gaz plus spécifique).
- PiSense Lite (BMP280 avec/sans capteur de gaz plus spécifique).

## Composants et développement

Par souci de facilité et afin de réduire les coûts, nous travaillerons sur la solution tout-en-un et gardons la seconde option avec choix de capteur plus spécifique comme dépassement.

- Raspberry Pi
  - Capteurs
    - Solution température, humidité, pression et eCO2 :
      - Bosch BME680 – Temperature, Humidity, Pressure and Gas Sensor
    - Capteur température, humidité et pression :
      - Bosch BME280 Environmental Sensor
    - Capteur température et pression :
      - Bosch BMP280 Digital Pressure Sensor
    - Capteur d’oxyde de Silicium :
      - Nova PM2.5 Sensor – SDS011
  - Site web ?
  - API ou développement applicatif Android ? *(voir page suivante)
    - API PushBullet (https://www.pushbullet.com/) Système de notification sur ordinateur et mobile pour prévenir des seuils/alertes. Possibilité de développer des fonctionnalités afin de demander le graphique des mesures de température, humidité et eCO2 des dernières 24h.
    - Application mobile Android sous React ou Android Studio

* L’utilisation de l’API, une application dédiée disponible sur appareil mobile ou un site internet sont des solutions viables. À voir si cela peut convenir pour les 2 clients respectifs.

L’intérêt de l’API PushBullet (https://docs.pushbullet.com/) est la facilité d’intégration avec un système d’automatisation ou l’interaction avec des capteurs.
L’ennui est la paramétrisation de la solution IoT nécessitant, par conséquent, quelques interactions utilisateur au préalable. Le gros avantage est que si un autre développeur désire implémenter quelque chose et interagir avec l’appareil, avec l’API PushBullet, c’est tout à fait possible.

Une autre solution serait, dès lors, de créer une application mobile, exclusivement sur Android, interagissant avec la solution IoT. Cette solution prendra un temps considérable et peut ne pas être intégralement finalisée dans les délais même si fonctionnelle.

## Précision des composants

Capteurs de Bosch
BMP280

- Plage de fonctionnement :
  - Pression : 300 – 1100 hPa
  - Température : -40°C à 85°C
- Précision absolue (0°C à 65°C) : +/- 1 hPa
- Pression de précision absolue : +/- 0,50 hPa
- Précision relative (25°C à 40°C) : 0,12 hPa (typique)
- Pression de précision relative : +/- 0,06 hPa
- Précision de la température : 0,01°C
- Temps de démarrage : 2ms
- Temps de réponse : 1 seconde
- Résolution des données :
  - Température : 0,01°C
  - Pression : 0,01 hPa (< 10 cm)
- Consommation de courant maximum : 2,7 µA
- Consommation de courant moyenne en mode veille : 0,1 µA
- Altimètre : 1 mètre D’après les premiers tests réalisés, son calcul dépend de la pression atmosphérique et n’est d’aucune utilité pour ce projet. Dès lors, à oublier.

#### BME280

Identique au capteur BMP280 sauf pour les points suivants :

- Plage de fonctionnement de l’humidité relative : 0% à 100%
- Précision de l’humidité : +/- 3% (hystérésis : +/- 1%)
- Consommation de courant maximum : 3.6µA

#### BME680

Identique aux capteurs BMP280 et BME280 sauf pour les points suivants :

- Plage de fonctionnement du VOCT et eCO2 : -40°C à 85°C
- Précision de l’humidité : +/- 3% (hystérésis : +/- 1,5%)
- Consommation de courant maximum : 3.7µA
- VOCT et eCO2 : capteur chaud = mesures et calculs précis. À tester pour s’assurer de sa fiabilité.

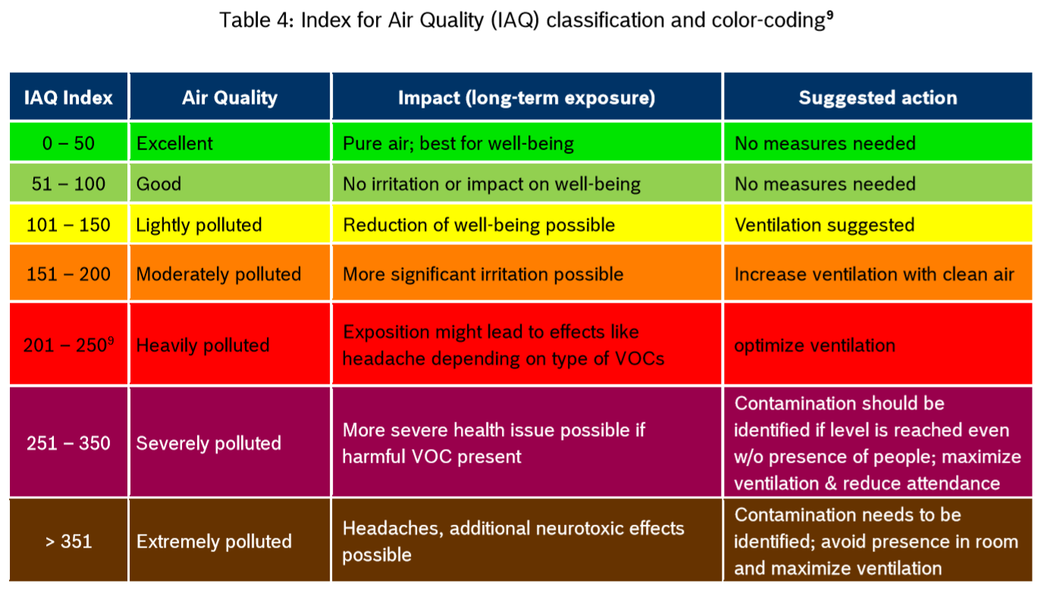
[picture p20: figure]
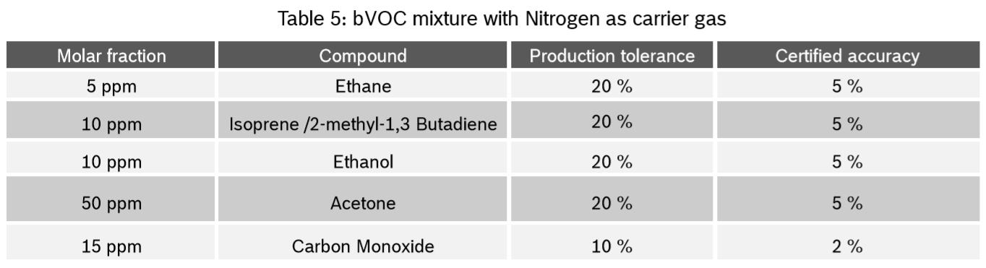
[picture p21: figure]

### Capteur SDS011 de Inovafit

- Sortie : PM2.5, PM10
- Plage de mesure : 0 – 999,9 µg/m³
- Tension d’entrée : 5V
- Consommation de courant maximum : 100mA
- Consommation de courant en mode veille : 2mA
- Temps de réponse : 1 seconde
- Fréquence de sortie des données : 1 fois par seconde
- Résolution du diamètre des particules : ≤ 0,3µm
- Erreur relative : 10%
- Plage de température : -20°C à +/- 50°C

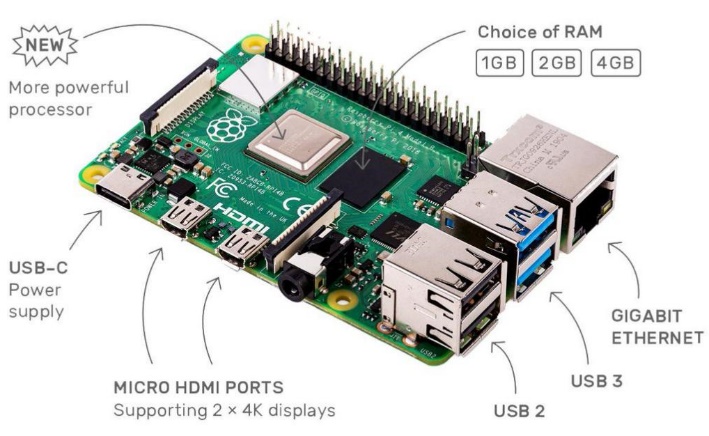
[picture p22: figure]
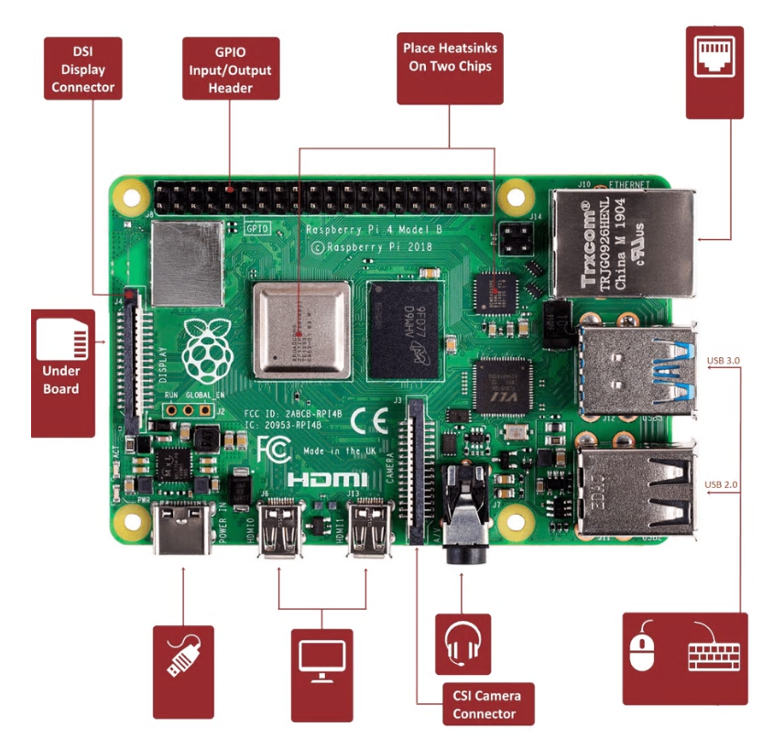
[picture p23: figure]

## Documentation liée à la Raspberry Pi 4

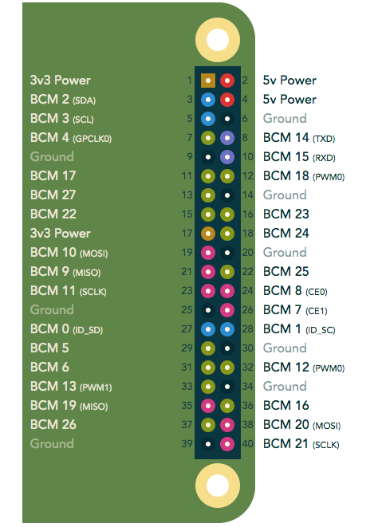
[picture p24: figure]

GPIO Header

https://pinout.xyz/ est un guide GPIO très complet pouvant grandement aider dans ce projet.

## Dépassement

- Dépassement : affichage Ce dépassement intégrerait un affichage directement au boîtier afin de permettre la lecture des données actuellement récupérée par les capteurs.
- Dépassement : Site web (intranet ?) Ce dépassement serait hébergé localement dans la Raspberry Pi.
  - Regroupe les informations de température, humidité et eCO2 afin de les afficher dans un graphique
  - Accès à l’historique des mesures prises des 30 derniers jours
- Dépassement : disponibilité des mesures via API/Cloud Cela permettrait à quiconque d’autorisé de récupérer les données récoltées et les intégrer dans une application d’un développeur tiers.
- Capteur de différents gaz, à voir pour un possible élargissement : https://playground.arduino.cc/Main/MQGasSensors/#list Conflit possible avec l’un des capteurs et moins pratique, car ne couvre pas différents éléments. À noter que le convertisseur analogique-digital MCP3008 et le convertisseur niveau logique TTL 3.3V-5V I2C seront nécessaire avec ce capteur, un système de multiplexage sera à mettre en place.

Page 2 sur 2

Travail de fin d’études (TFE) EPHEC 2019/2020 Melvin Campos Casares Solution IoT : PiSense

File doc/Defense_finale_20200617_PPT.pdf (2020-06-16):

## Juin

2020

# Système modulable de prises de mesures environnementales sur Raspberry Pi avec système d’affichage

## EPHEC 2019-2020

Melvin Campos Casares | 3TL2

Rapporteur : Arnaud Dewulf

# Défense de travail de fin d’études

# Plan

Introduction; Développement; Sécurité et rapidité; Pistes d’amélioration; Boîtier pour impression 3D; Conclusion

Système modulable de prises de mesures environnementales avec affichage | 2

# Introduction

3

## Est-il possible d’imaginer une solution de petite taille permettant la récupération des données environnementales ?

Système modulable de prises de mesures environnementales avec affichage

# Développement


### Divisé en 3 parties distinctes

### Réunions régulières avec le client (Dreamnet SRL)

- Méthodologie proche aux méthodes Agile/SCRUM
- Développement en 3 étapes :
- Raspberry Pi
- Site internet
- Base de données et API
Système modulable de prises de mesures environnementales avec affichage | 4


AJOUTER UN PIED DE PAGE | 5

# Sécurité et rapidité


Système modulable de prises de mesures environnementales avec affichage | 6

# Sécurité et rapidité


Système modulable de prises de mesures environnementales avec affichage | 7

# Piste d’amélioration

## Quelques idées d’implémentation future

# Idées en cours

- Mise en place d’un système de connexion utilisateur,
- Accès par intranet aux données de l’appareil de suivi,
- Modélisation 3D d’un boîtier adapté au projet et pouvant être imprimé.

# Idées pouvant être envisagées

- Application permettant la configuration rapide
de la Raspberry Pi :
- Configuration de la connectivité réseau Wi-Fi,
- Modification de l’intervalle entre chaque prise de mesures.
- Système de commande complète en ligne en lieu et place de la prise de contact avec l’entreprise.
Système modulable de prises de mesures environnementales avec affichage | 8


# Boîtier 3D

## Boîtier prévu pour l’impression 3D

Système modulable de prises de mesures environnementales avec affichage | 9

# Conclusion

## - Amélioration dans le langage de programmation Python :

- Apprentissage du framework Flask,
- Compréhension des différences entre Python 2.x et Python 3.x,
- Intérêt du choix de modules et librairies adaptées.

## - Professionnalisme dans les échanges avec les clients - Cahier de charges revu suite aux problèmes rencontrés avec la pandémie

- Appareil de suivi environnemental intégralement fonctionnel,
- API et base de données fonctionnels,

## - Environnement web présentant les interactions, mais ne dispose pas de gestion de

notification sur base d’alertes personnalisées ni de connexion/création de comptes.

Système modulable de prises de mesures environnementales avec affichage | 10

# MERCI DE VOTRE ATTENTION !

# Melvin Campos Casares

### Système modulable de prises de mesures environnementales sur Raspberry Pi avec système d’affichage

Travail de fin d’études présenté en vue de l’obtention du diplôme de bachelier en Informatique et Systèmes orientation Technologie de l’informatique

ECOLE PRATIQUE DES HAUTES ETUDES COMMERCIALES

## EPHEC

Avenue du Ciseau, 15
1348 Louvain-la-Neuve

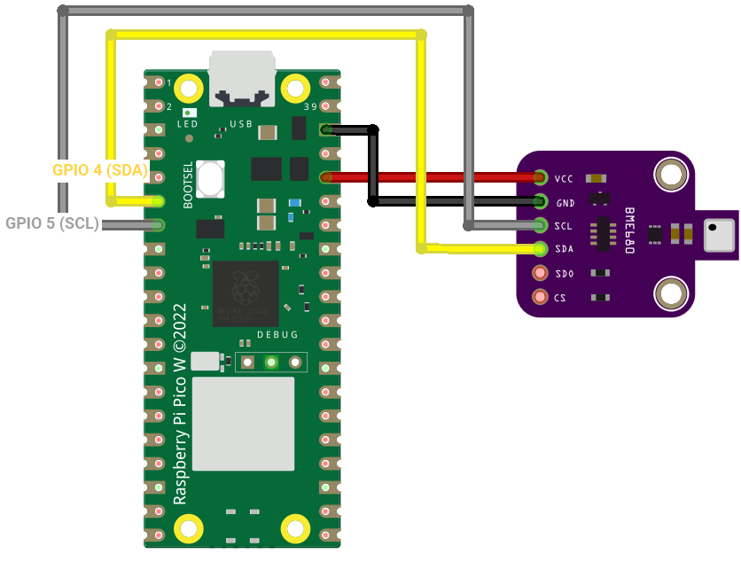
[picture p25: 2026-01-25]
PiSense-Lite with Home Assistant/pinout-diagram-RPi-Pico-bme680.png

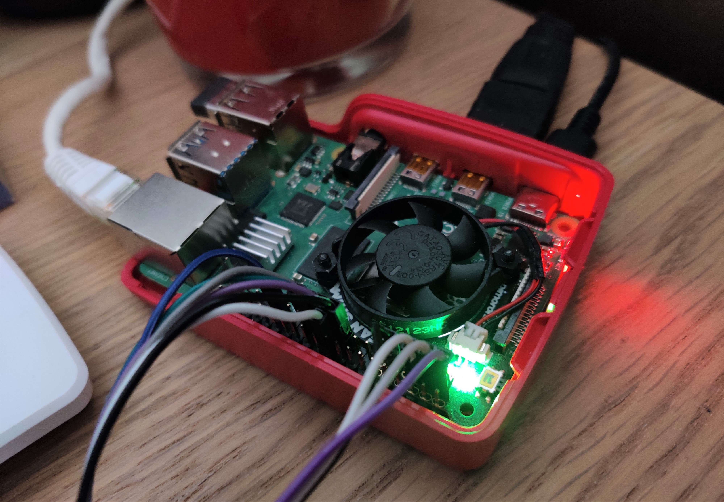
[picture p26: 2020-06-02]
doc/Pictures/RPi4+caseV1.jpg

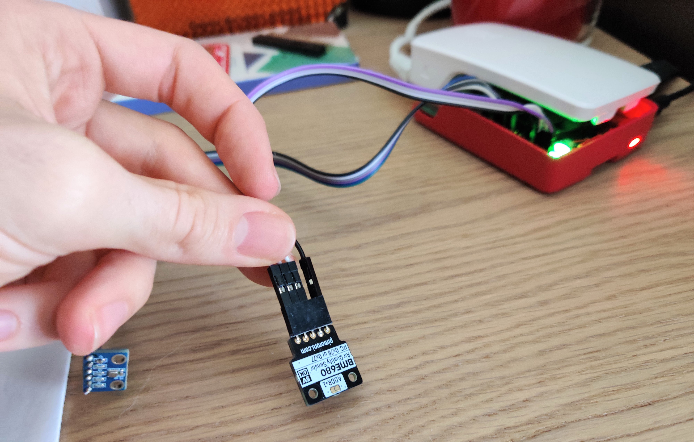
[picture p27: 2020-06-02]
doc/Pictures/RPi4+caseV1+BME280-BME680.jpg

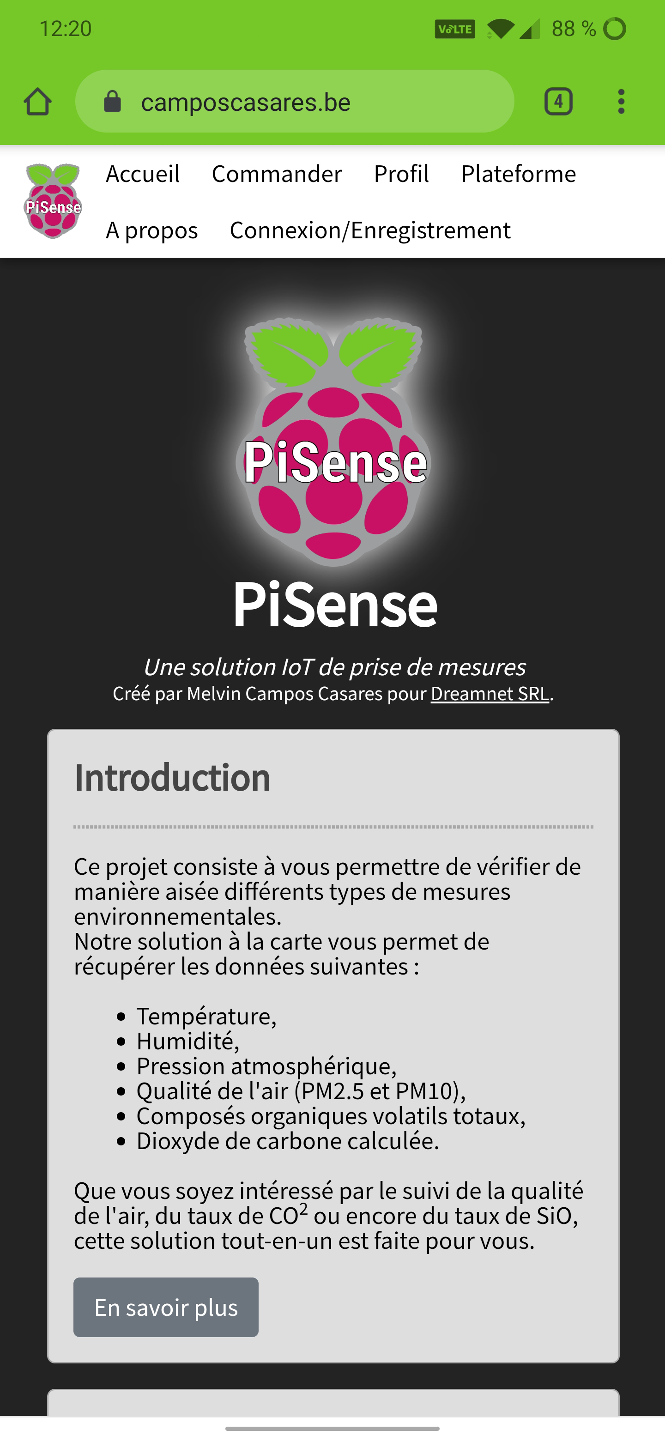
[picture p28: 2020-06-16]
doc/Pictures/web-platformMobile-metaThemeColor.jpg

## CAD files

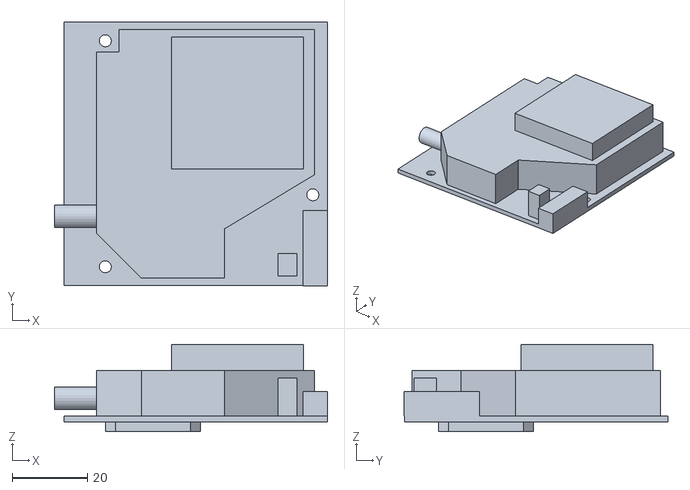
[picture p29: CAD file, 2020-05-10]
3D-box/appareil pour test mesure/Nova PM SDS011 Sensor (simplified).stl
72.5 x 70.1 x 23.2

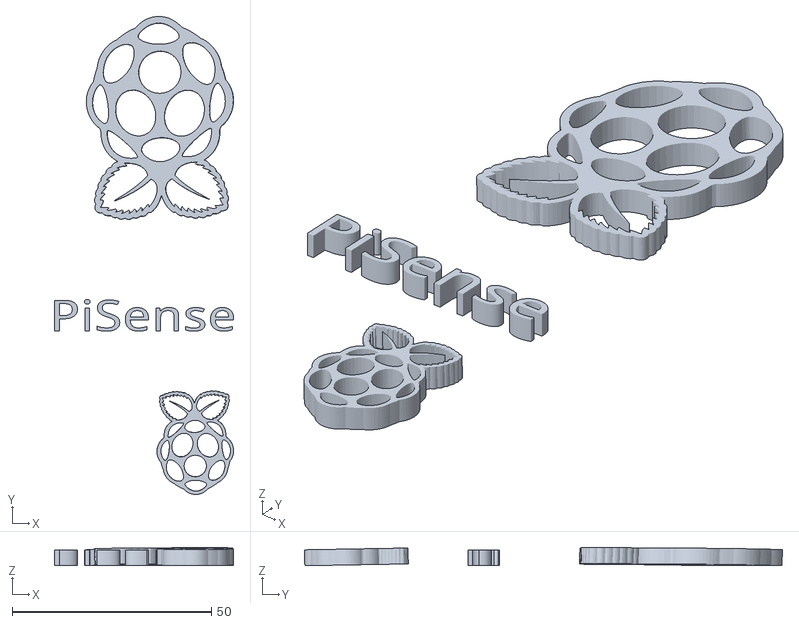
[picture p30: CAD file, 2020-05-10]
3D-box/PiSense-logo-to-put-in-color.stl
45.0 x 120.0 x 4.64

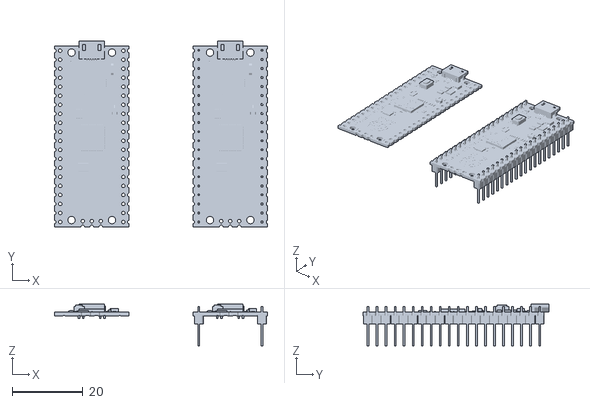
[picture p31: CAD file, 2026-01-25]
PiSense-Lite with Home Assistant/3D-box/Raspberry Pi Pico.stl
60.0 x 52.3 x 11.7

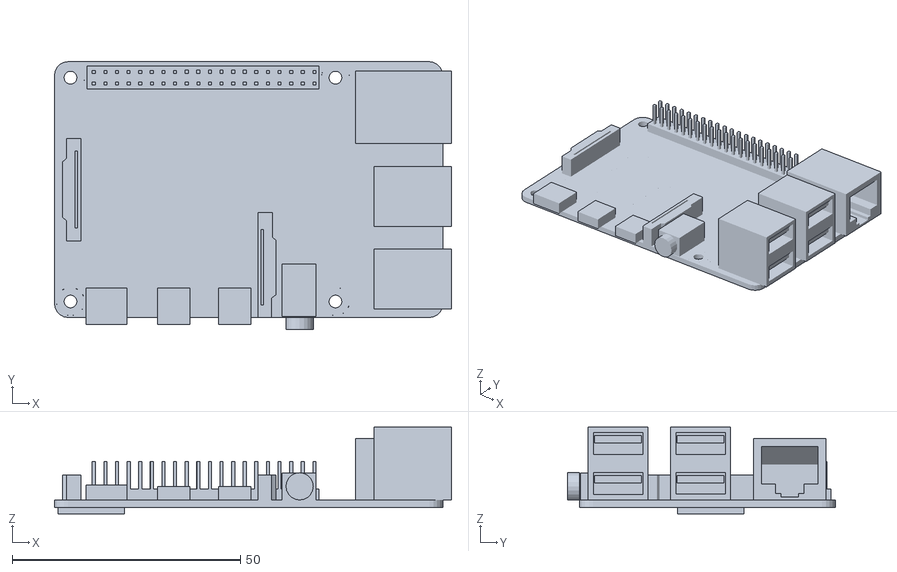
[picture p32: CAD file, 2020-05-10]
3D-box/appareil pour test mesure/Raspberry Pi 4 B.stl
86.9 x 58.6 x 19.0

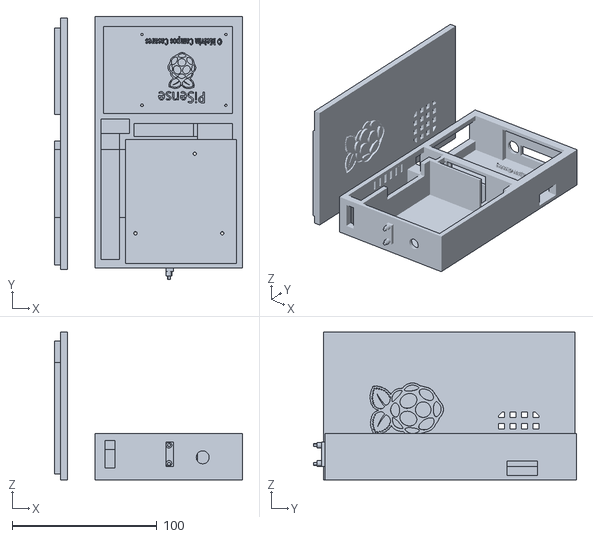
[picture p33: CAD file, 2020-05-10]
3D-box/PiSense-box.stl
130.0 x 182.0 x 102.0

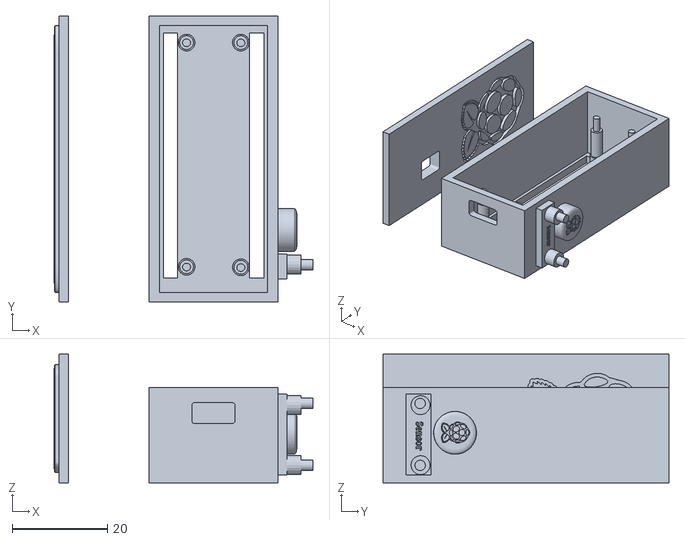
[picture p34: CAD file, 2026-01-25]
PiSense-Lite with Home Assistant/3D-box/PiSense Lite box.stl
54.4 x 60.0 x 27.0

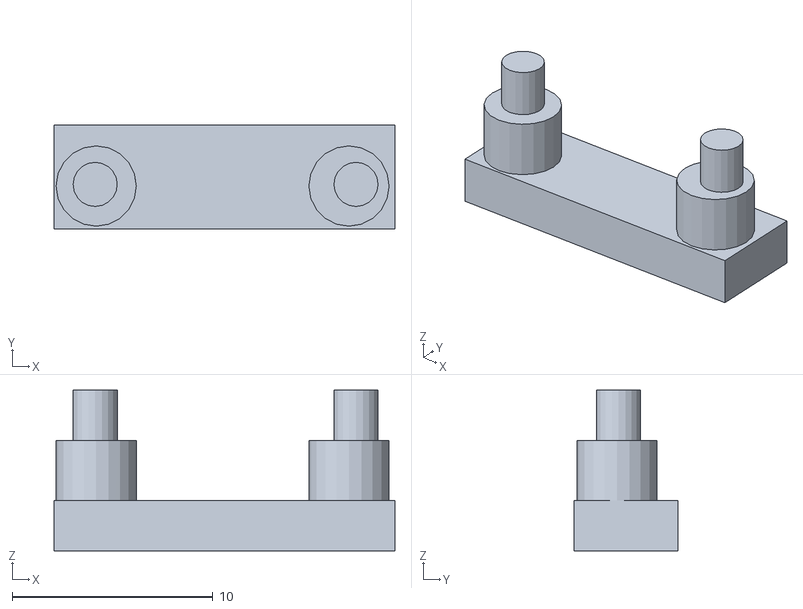
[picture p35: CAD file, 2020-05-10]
3D-box/appareil pour test mesure/BME680 Sensor Mount Pillars.stl
17.0 x 5.20 x 8.00

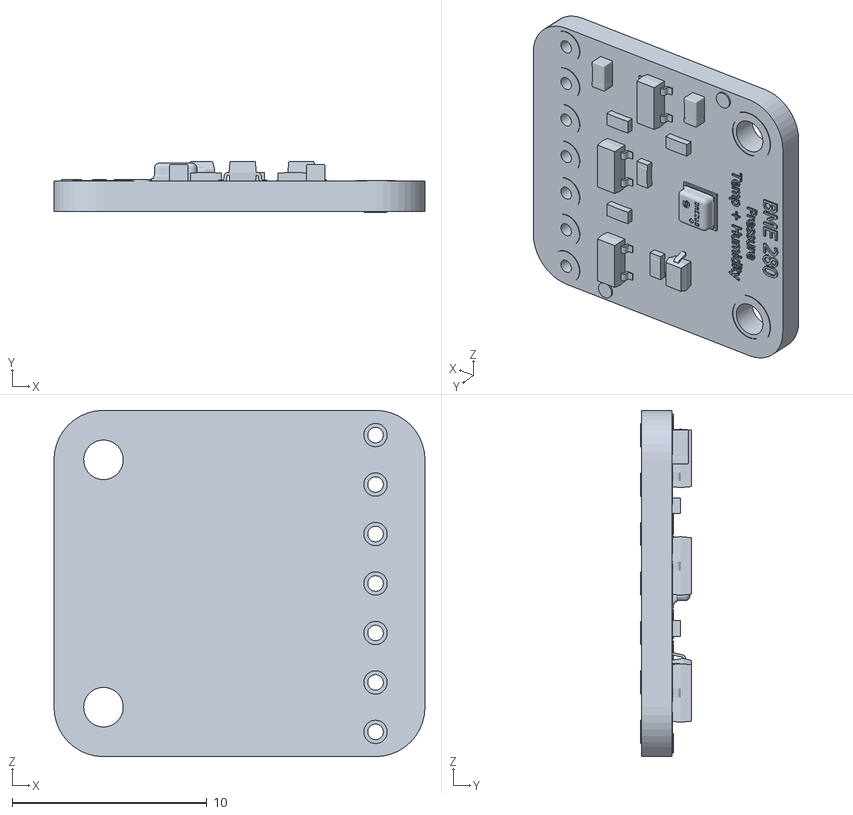
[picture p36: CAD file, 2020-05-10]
3D-box/appareil pour test mesure/User Library-BME280-2.STL
19.1 x 2.61 x 17.8

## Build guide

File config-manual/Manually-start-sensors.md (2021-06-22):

---
subtitle: Manually start sensors on the device
date: 20 june 2021
keywords: [PiSense, IoT, sensors, dev, tutorial, configuration, console, python]
footer-left: Manual - Manually start sensors on Raspberry Pi devices
toc-title: Manual - how to manually start sensors onto Raspberry Pi devices
---

# Manually launch sensors onto Raspberry Pi devices

Once the Raspberry Pi has started and you're connected via *VNC Viewer* or *TeamViewer*, launch **Konsole** to access Linux/Raspbian terminal.

* Go to the right folder: `cd Git/tfe-PiSense/sensors/`,
* Launch BME680/BME280/BMP280 code according to the sensor connected on PiSense.
  Here's with the BME680 sensor: `sudo python3 bme680/bme680sensor.py`
* Open a new tab in Konsole: <kbd>New Tab (Ctrl+Shift+T)</kbd> > <kbd>Fish (F)</kbd>,
* Launch SDS011 code if the sensor is connected on PiSense: `sudo python sds011/sds011sensor.py`.

That's it!

## Automatically launch sensors onto Raspberry Pi devices

If you want to automatically launch both BME680 and SDS011 sensor, a small script is available and runnable inside root folder.

* BME680 + SDS011 launcher: `pi_bme680-sds011launcher.sh`
* BME280 + SDS011 launcher: `pi_bme280-sds011launcher.sh`
* BMP280 + SDS011 launcher: `pi_bmp280-sds011launcher.sh`

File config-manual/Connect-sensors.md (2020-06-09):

---
subtitle: Manual connect sensors on Raspberry Pi devices
date: 9 june 2019
keywords: [TFE, graduation, work, PiSense, IoT, sensors, dev, tutorial, connect, sensor, EPHEC, 3TI]
footer-left: Manual - connect sensors on Raspberry Pi devices
toc-title: Manual - how to connect the different sensors onto Raspberry Pi devices
---

# Connect one or multiple sensors onto Raspberry Pi devices

Currently, this project support the following sensors:

* _Nova SDS011:_ Fine particles in suspension (PM2.5, PM10).
* _Bosch BMP280 (based on Adafruit library):_ temperature and humidity.
* _Bosch BME280 (based on Adafruit library):_ temperature, humidity, atmospheric pressure.
* _Bosch BME680 (based on Pimoroni library):_ temperature, humidity, gas (TVOC, eCO2), atmospheric pressure.

If for any reason you need to connect one of the sensors, here you will find a diagram to help you find out how to process it.

As it's meant to be connected on Raspberry Pi devices (this project is working on such device), take the board of the Raspberry in front of you with the GPIO connectivity port at your upper right side.
Like that, the diagram will correspond to your GPIO port.

## Nova SDS011 sensor

For this sensor, we are using the included Serial to USB adapter.

* Simply connect the cable on the SDS011 module on one side,
* On the other side, connect the cable on the USB adapter,
* Connect the adapter on one of the USB ports available on your Raspberry Pi device.
* You are done.

## Bosch BMP280 sensor

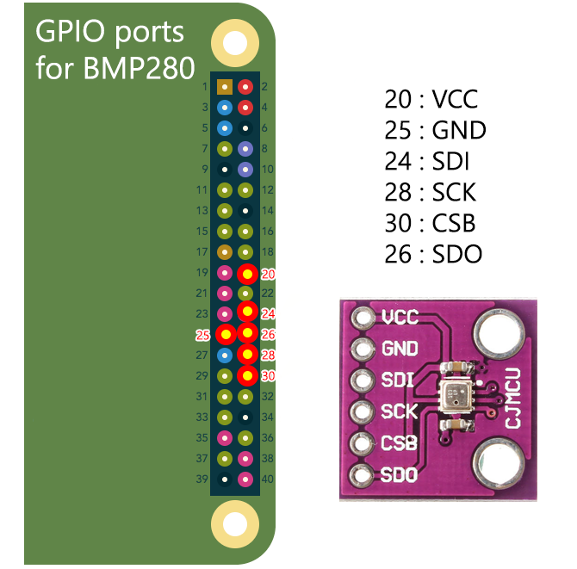
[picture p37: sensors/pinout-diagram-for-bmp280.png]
Bosch BMP280 sensor GPIO connect diagram


## Bosch BME280 sensor

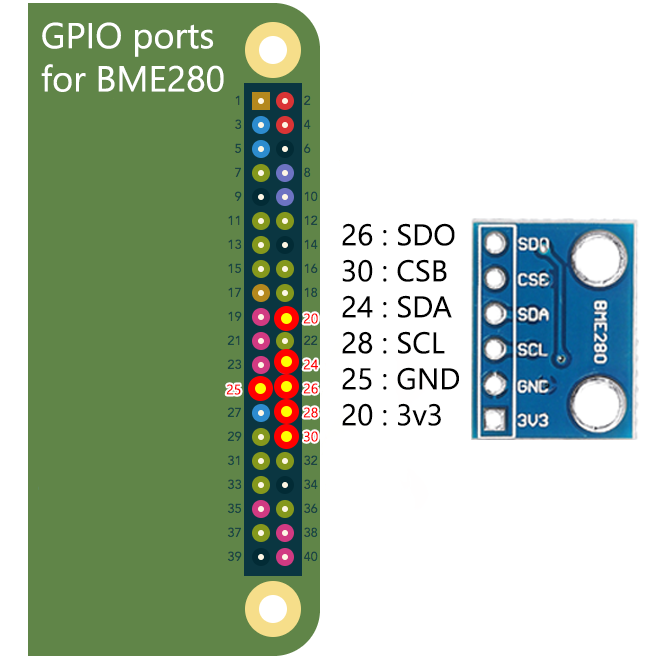
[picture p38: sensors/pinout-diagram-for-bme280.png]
Bosch BME280 sensor GPIO connect diagram


## Bosch BME680 sensor

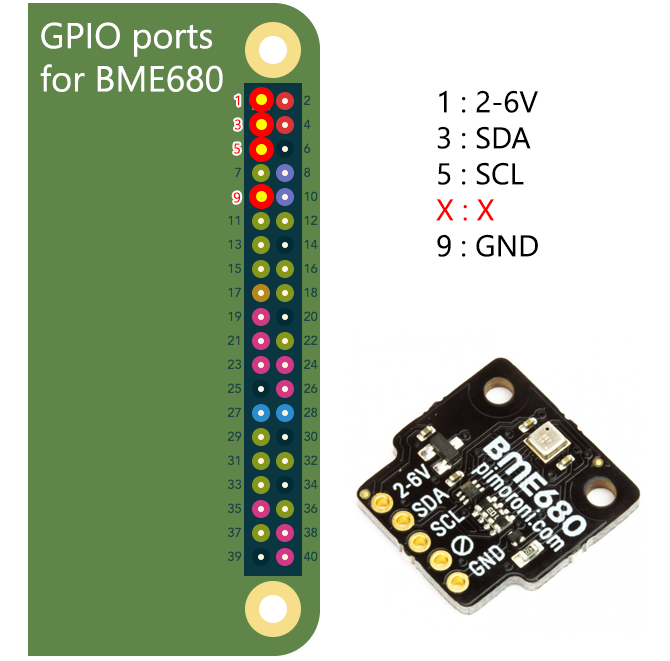
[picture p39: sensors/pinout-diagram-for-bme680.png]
Bosch BME680 sensor GPIO connect diagram


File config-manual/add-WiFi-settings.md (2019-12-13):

---
subtitle: Manual WiFi configuration on Raspberry Pi devices
date: 13 december 2019
keywords: [TFE, graduation, work, PiSense, IoT, sensors, dev, tutorial, WiFi, configuration, EPHEC, 3TI]
footer-left: Manual - WiFi configuration on Raspberry Pi devices
toc-title: Manual - how to manually configure WiFi networks onto Raspberry Pi devices
---

# Add WiFi network info onto Raspberry Pi devices

Create a file in the root of boot called: `wpa_supplicant.conf` (instructions below).
Then, paste the following into it (adjusting for your [ISO 3166-1 alpha-2 country code](https://en.wikipedia.org/wiki/List_of_ISO_3166_country_codes), network name and network password):

```conf
country=BE
ctrl_interface=DIR=/var/run/wpa_supplicant GROUP=netdev
update_config=1

network={
    ssid="NETWORK-NAME"
    psk="NETWORK-PASSWORD"
}
```

Save the file and reboot the Raspberry Pi.

## Access the boot folder

### Raspbian instructions

We suppose you're either directly working on the Raspberry Pi or via SSH, but always under root access.

1. Open a terminal
2. Go to the boot folder : `cd \boot\`
3. Create the new file either with vim or nano (example with vim): `sudo vim wpa_supplicant.conf`
4. Don't forget to save the file before quitting vim or nano

### Mac instructions

For those instructions, we suppose you burned fresh Raspbian on a microSD card.

1. Create a new empty file that will hold network info
2. Via terminal : `touch /Volumes/boot/wpa_supplicant.conf`
3. Edit the file and then save it.

### Windows instructions

1. Run Notepad
2. Paste in the contents holding network info
3. Click **File / Save as...**
4. Be sure to set **Save as type** to **All files** (so the file is NOT saved with a .txt extension)
5. Call the file `wpa_supplicant.conf` and save it
6. Close the file

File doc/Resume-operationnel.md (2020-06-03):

---
subtitle: Résumé opérationnel du travail de fin d'études
date: Juin 2020
keywords: [TFE, graduation, work, PiSense, IoT, sensors, dev, operational, summary, TFE, graduation, résumé, opérationnel, EPHEC, 3TI]
header-left: Système modulable de prises de mesures environnementales avec affichage
footer-left: Résumé opérationnel du TFE
footer-center: EPHEC 2019/2020
toc: false
---

# Problématique et objet

Dans le cadre d’une requête professionnelle demandée par la société Dreamnet SRL, un système IoT permettant le suivi de la température, de l’humidité et du taux de CO2 au sein d’une pièce est requis afin de répondre à un projet futur.
Il permettra l’optimisation de l’environnement du personnel.

Sur base de premiers retours avec le professeur A. Dewulf, un intérêt est également présent pour détecter l’Oxyde de Silicium auprès d'une carrière.
Cela permettra au client de prévenir de tous risques liés à une présence d’Oxyde de Silicium à un taux élevé.

Des études ont prouvé qu’une pièce à bonne température ambiante et avec une qualité d’air adéquate permet d’aider à la concentration, améliorer l’état de santé ainsi que la productivité de l’être humain.
Il semblerait que dans le milieu professionnel, la pollution atmosphérique est un facteur aggravant pour les pathologies respiratoires.

# Méthodologie

Des réunions régulières ont été prévues avec Dreamnet SRL afin de s'assurer que la direction suivie soit la bonne.
La méthodologie suivie s'apparente aux méthodologies Agile et plus précisément Scrum.
Avec la période compliquée que nous avons subi, certaines contraintes ont été rencontrées, forçant de changer la manière de s'organiser ainsi que de la mise en place des réunions.

Le développement a débuté sur la partie IoT avec la Raspberry Pi pour ensuite laisser place au développement du site internet et après de l'API ainsi que d'une base de données pour la communication et stockage des données.

# Résultats

La partie IoT avec la Raspberry Pi est finalisée, le site internet présente des graphiques, l'API et la base de données sont fonctionnels.
La partie gestion d'enregistrement et connexion utilisateur n'est pas exploitable, mais la structure est présente.
Le site internet est accessible à l'adresse suivante : <https://www.camposcasares.be/>

# Recommandations

Comme convenu avec le client, la partie gestion d'enregistrement/connexion utilisateur nécessite des modifications afin d'être fonctionnelle. La structure est présente dans la base de données, mais des ajustements sont nécessaires côté site internet.

Un système de commande complète en ligne pourrait être envisagé, tout comme une application facile d'utilisation permettant la configuration de la Raspberry Pi.
La modélisation 3D d'un boitier adapté a été réalisée ; il pourrait être utilisé pour la commercialisation de ce projet.

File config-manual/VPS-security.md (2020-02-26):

---
subtitle: Manual VPS security configuration
date: 26 february 2020
keywords: [TFE, graduation, work, PiSense, IoT, sensors, dev, tutorial, security, connection, configuration, EPHEC, 3TI]
footer-left: Manual - VPS security configuration
toc-title: Manual - how to manually configure the security onto VPS
---

# VPS security configuration

## Create a new user

> NOTE: The root administrator is created by default on UNIX systems, he is the user who has the most rights on the system.
> It is not recommended, or even dangerous, to leave a VPS accessible only through this user, who can perform irreversible operations on the server.

We will therefore create a user with restricted access to perform common tasks and give administrator rights:

* `adduser user`
* Enter a secure password and press <kbd>ENTER</kbd> for each question to pass (or give the information asked), then validate the information with <kbd>Y</kbd>.
* `usermod -aG sudo user`

Commands requiring administrator rights will be preceded by the keyword `sudo` and the user's password will be requested.

### SSH key for user connection

* `ssh-keygen -b 4096`
  * It will ask for a location where to save it: `/home/user/.ssh/id_rsa`.
  * It will ask for a passphrase, give it and then press <kbd>ENTER</kbd>.
* `ssh-copy-id user@vpsXXXX.ovh.net`
  * It is also possible to perform this operation manually:
    ```sh
    cat ~/.ssh/id_rsa.pub | ssh user@vpsXXXX.ovh.net "mkdir -p ~/.ssh && cat >> ~/.ssh/authorized_keys"
    ```

### Connect to the VPS with the SSH key

* `ssh user@vpsXXXX.ovh.net`

On the first connection, a confirmation message will appear to add the fingerprint of the host inside the `~/.ssh/known_hosts` file.

You will have a message like this one:
```
The authenticity of host 'vpsXXXX.ovh.net (xxx.xxx.xxx.xxx)' can't be established.
ECDSA key fingerprint is SHA256:*******************************************.
Are you sure you want to continue connecting (yes/no)?
```

Simply enter `yes` and press <kbd>ENTER</kbd> to connect yourself.
If you gave a password to your ssh account, it will be prompted.

### Change root password

Even though we are going to block tuhe user *root* on SSH access, it's always better to change his password for security purpose.

* `passwd root`

The system will then ask to enter a new password twice to validate it.
For security reasons, it will not be displayed when writing.
You will therefore not be able to see the characters entered.
It is very important to use a strong password.

> NOTE: A strong password is greater than 8 characters.
> It must combine lowercase, uppercase letters, numbers, special characters and/or accented letters.
> But also avoid using dictionary words, names/first names, company name, user name ... The deliberate use of spelling mistakes is a good way to easily secure a password.

## SSH connection (+ deactivate SSH access for root user)

It is also recommended to disable direct root user access via the SSH protocol.

To perform this operation, we first need to create a new user with granted administrator rights and copy the SSH key before modifying the SSH configuration file like below.

* `sudo vim /etc/ssh/sshd_config`
* Change or add those lines at the end of the configuration file to match with here:
  * `PermitRootLogin no`
  * `DenyUsers root`
  * `PasswordAuthentication no`
* `/etc/init.d/ssh restart`

\pagebreak

## Fail2Ban

Fail2Ban is an intrusion prevention framework whose purpose is to block unknown IP addresses that try to enter your system.
This package is recommended, even essential, to protect ourself against any attempt to brute force on our services.

> NOTE: Fail2Ban scans the logs and prohibits IP addresses which display malicious signs (too many password failures, wrong username ...).
> In general, Fail2Ban is used to update the rules of the firewall to reject IP addresses for a specified period of time, although any other arbitrary action can also be configured.
> On the other hand, Fail2Ban comes with pre-configured filters for different services (Apache, NGINX, mail, FTP, SSH, etc.).

Here's what has been done with Fail2Ban:

* `sudo apt-get install fail2ban`
* `sudo vim /etc/fail2ban/jail.conf`
  * ```conf
    # findtime is the period of examination of logs in seconds.
    # bantime is a specified time for a banned IP in seconds.
    [DEFAULT]
    ignoreip = 127.0.0.1/8 192.168.1.1/24 10.8.0.1/16
    findtime = 3600
    bantime = 86400
    ```
* `sudo vim /etc/fail2ban/jail.d/defaults-debian.conf`
  * ```conf
    # 10 requests in 2 min -> ban for 30 minutes
    [sshd]
    enabled = true
    maxretry = 10
    findtime = 180
    bantime = 1200

    [sshd-ddos]
    enabled = true

    [recidive]
    enabled = true

    [nginx]
    enabled = true
    ```
* sudo /etc/init.d/fail2ban restart

\pagebreak

## Firewall

### Uncomplicated Firewall (ufw)

* `sudo ufw allow {{80}}`
* `sudo ufw allow {{443}}`
* `sudo ufw allow proto {{tcp}} from {{any}} to {{any}} port {{22}}`
* `sudo ufw deny proto {{udp}} from {{any}} to {{any}} port {{22}}`
* `sudo ufw enable`

### OVH

> Deactivated

## Secure shared memory

Shared memory can be used during an attack on a running service.

In order to secure the shared memory:

* `sudo vim /etc/fstab`
* `tmpfs   /run/shm    tmpfs   defaults,noexec,nosuid  0   0`

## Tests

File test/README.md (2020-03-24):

# Installation process for SDS011 (sds011test.py)

* `sudo apt install git-core python-serial python-enum lighttpd`
* `dmesg` and check the line with interface ttyUSB0 (normal last line)

In order for the sds011test.py script to run without errors, some changes:

* `sudo chown pi:pi /var/www/html/`
* `echo [] > /var/www/html/aqi.json`
* `chmod +x sds011test.py`
* Script is now runnable: `./sds011test.py`

# Installation process for SDS011 with screen (sds011test-withscreen.py)

* `sudo apt-get install python-numpy python-scipy python-matplotlib`
* `sudo pip3 install sds011` & `sudo pip install sds011`
* `sudo pip3 install pylab`

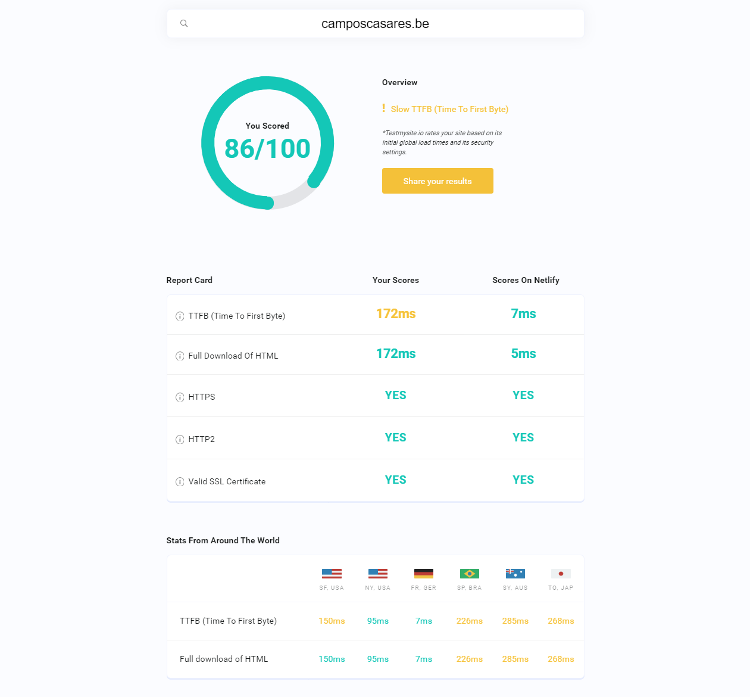
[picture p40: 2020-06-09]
doc/SSL_Labs+Security_headers/Testmysite.io-NetlifySpeedtest-camposcasares.be.png

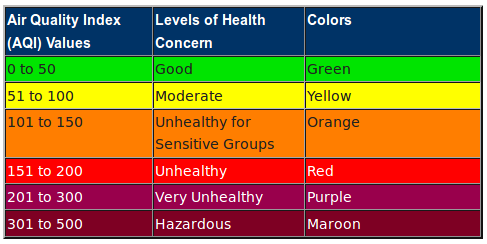
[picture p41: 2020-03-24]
test/sds011-html/air-quality-index.png

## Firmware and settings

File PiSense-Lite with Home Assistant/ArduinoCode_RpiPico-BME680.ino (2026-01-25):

/*********
  Title: Raspberry Pi Pico WH with Pimoroni BME680 sensor (from Bosch)
  Author: Melvin Campos Casares
  Project details: https://github.com/melvinmajor/tfe-PiSense
  -----
  Permission is hereby granted, free of charge, to any person obtaining a copy of this software and associated documentation files.
  The above copyright notice and this permission notice shall be included in all copies or substantial portions of the Software.
*********/

#include <Wire.h>
#include <Adafruit_Sensor.h>
#include "Adafruit_BME680.h"
#include <WiFi.h>
#include <PubSubClient.h>
#include <WiFiClientSecure.h>

#define SEALEVELPRESSURE_HPA (1013.25)

// Replace with your WiFi credentials
const char* ssid = "YourSSID";
const char* password = "YourPassword";

// MQTT Broker
const char* mqtt_devicename = "PicoBME680"; // Name of the device in MQTT
const char* mqtt_server = "192.168.xxx.xxx"; // IP of the MQTT broker (Home Assistant)
const int mqtt_port = 1883; // Default port of Mosquitto MQTT is 1883. The secure one with SSL/TLS is 8883.
const char* mqtt_user = "mqttUserName";
const char* mqtt_password = "mqttPassword";
const char* availabilityTopic = "home/pisense/status";


const unsigned long measurementInterval = 300000; // 5 minutes
unsigned long lastMeasurementTime = 0;
bool firstRunOrReconnect = true;
unsigned long lastStatusUpdateTime = 0;
const unsigned long statusUpdateInterval = 60000; // 1 minute
unsigned long startAttemptTime = 0; // for the reconnection chrono
unsigned long reconnectDelay = 1000; // Start with 1 second
const unsigned long maxReconnectDelay = 10000; // Maximum delay is 10 seconds
const unsigned long connectionTimeout = 60000; // timeout for the reconnection tentative
unsigned long previousBlinkTime = 0; // Store time of last blink
int blinkCount = 0;  // Count the blink
int blinkState = LOW;  // Actual state of the LED (on or off)
unsigned long previousWiFiAttemptTime = 0;
bool wifiLedState = LOW;
unsigned long previousReconnectTime = 0;
unsigned long previousBlinkTimeReconnect = 0;
unsigned long previousBlinkTimeMeasurement = 0;
bool blinkMeasurementState = LOW;

Adafruit_BME680 bme; // I2C (default pins for Raspberry Pi Pico: GPIO 4 (SDA), GPIO 5(SCL)
WiFiClient espClient;
PubSubClient client(espClient);
WiFiClientSecure secureClient; // Secured client for SSL/TLS


void blinkLED(unsigned long interval) {
    if (millis() - previousBlinkTime >= interval) {
        previousBlinkTime = millis();
        blinkState = !blinkState;
        digitalWrite(LED_BUILTIN, blinkState);
    }
}

void blinkError(int times) {
  unsigned long currentMillis = millis();
  
  if (blinkCount < times) {
    if (currentMillis - previousBlinkTime >= 300) {  // If 300ms passed since last blink
      previousBlinkTime = currentMillis;
      blinkState = !blinkState;  // Change state of LED (on/off)
      digitalWrite(LED_BUILTIN, blinkState);
      
      if (blinkState == LOW) {
        blinkCount++;  // Increment count once LED is off
      }
    }
  }
}

void setup_wifi() {
  Serial.println();
  Serial.print("Connecting to ");
  Serial.println(ssid);

  WiFi.begin(ssid, password);

  while (WiFi.status() != WL_CONNECTED) {
    unsigned long currentMillis = millis();

    if (currentMillis - previousWiFiAttemptTime >= 100) {
      previousWiFiAttemptTime = currentMillis;
      digitalWrite(LED_BUILTIN, wifiLedState);
      wifiLedState = !wifiLedState;  // Change state of the LED every 100ms
    }
    Serial.print(".");
  }

  Serial.println("");
  Serial.println("WiFi connected!");
  Serial.print("IP address: ");
  Serial.println(WiFi.localIP());
}

void checkWiFi() {
  if (WiFi.status() != WL_CONNECTED) {
    Serial.println("WiFi disconnected, reconnecting...");
    WiFi.begin(ssid, password);
    while (WiFi.status() != WL_CONNECTED) {
      delay(1000);
      Serial.print(".");
    }
    Serial.println("WiFi reconnected!");
    firstRunOrReconnect = true;
  }
}

void reconnect() {
  startAttemptTime = millis(); // init the chrono
  Serial.println("Starting MQTT reconnection process...");

  // Loop until we're reconnected or timeout reached
  while (!client.connected()) {
    Serial.print("Attempting MQTT connection... ");

    unsigned long currentMillis = millis();
    if (currentMillis - previousBlinkTimeReconnect >= 100) {
      previousBlinkTimeReconnect = currentMillis;
      digitalWrite(LED_BUILTIN, !digitalRead(LED_BUILTIN));  // Change state of LED
    }
    
    // Attempt to connect and define disponibility message (birth) + LWT
    if (client.connect(mqtt_devicename, mqtt_user, mqtt_password, availabilityTopic, 1, true, "offline")) {
      Serial.println("Connected!");
      client.publish(availabilityTopic, "online", true);
      client.subscribe("home/pisense/command"); // Resubscribe to topic
    } else {
      Serial.print("Failed to connect, state ");
      Serial.println(client.state());
      blinkError(3); // Blink 3 times to show there is an error

      if (!client.connected()) {
        reconnectDelay = (reconnectDelay * 2 > maxReconnectDelay) ? maxReconnectDelay : reconnectDelay * 2;
        delay(reconnectDelay);
      } else {
        reconnectDelay = 1000; // Reset delay on successful connection
      }

      // Timeout after 60 seconds
      if (millis() - startAttemptTime > connectionTimeout) {
        Serial.println("Timeout reached, skipping reconnection for now...");
        return;
      }
    }
  }
}

void callback(char* topic, byte* payload, unsigned int length) {
  Serial.print("Message from topic: ");
  Serial.println(topic);
  
  // Convert payload to varchar
  char message[length + 1];  // Add 1 for the end chararcter '\0'
  for (unsigned int i = 0; i < length; i++) {
    message[i] = (char)payload[i];
  }
  message[length] = '\0';  // End chain
  
  // Check message and execute related action
  if (strcmp(message, "ON") == 0) {
    digitalWrite(LED_BUILTIN, HIGH);  // Turn on LED
    Serial.println("LED ON");
  } else if (strcmp(message, "OFF") == 0) {
    digitalWrite(LED_BUILTIN, LOW);  // Turn off LED
    Serial.println("LED OFF");
  } else {
    Serial.println("Unrecognized command from broker...");
  }
}

void sendDiscoveryPayloads() {
  String tempPayload = R"({
    "name": "PiSense Temperature",
    "state_topic": "home/pisense/bme680",
    "unit_of_measurement": "°C",
    "value_template": "{{ value_json.temperature }}",
    "device_class": "temperature",
    "unique_id": "bme680_temperature",
    "availability_topic": "home/pisense/status",
    "device": {
      "identifiers": ["bme680"],
      "name": "PiSense",
      "model": "BME680",
      "manufacturer": "Bosch"
  })";
  client.publish("homeassistant/sensor/pisense_temperature/config", tempPayload.c_str(), true);

  String humPayload = R"({
    "name": "PiSense Humidity",
    "state_topic": "home/pisense/bme680",
    "unit_of_measurement": "%",
    "value_template": "{{ value_json.humidity }}",
    "device_class": "humidity",
    "unique_id": "bme680_humidity",
    "availability_topic": "home/pisense/status",
    "device": {
      "identifiers": ["bme680"],
      "name": "PiSense",
      "model": "BME680",
      "manufacturer": "Bosch"
  })";
  client.publish("homeassistant/sensor/pisense_humidity/config", humPayload.c_str(), true);

  String pressPayload = R"({
    "name": "PiSense Pressure",
    "state_topic": "home/pisense/bme680",
    "unit_of_measurement": "hPa",
    "value_template": "{{ value_json.pressure }}",
    "device_class": "pressure",
    "unique_id": "bme680_pressure",
    "availability_topic": "home/pisense/status",
    "device": {
      "identifiers": ["bme680"],
      "name": "PiSense",
      "model": "BME680",
      "manufacturer": "Bosch"
  })";
  client.publish("homeassistant/sensor/pisense_pressure/config", pressPayload.c_str(), true);

  String gasPayload = R"({
    "name": "PiSense Gas Resistance",
    "state_topic": "home/pisense/bme680",
    "unit_of_measurement": "kOhms",
    "value_template": "{{ value_json.gas }}",
    "unique_id": "bme680_gas_resistance",
    "availability_topic": "home/pisense/status",
    "device": {
      "identifiers": ["bme680"],
      "name": "PiSense",
      "model": "BME680",
      "manufacturer": "Bosch"
  })";
  client.publish("homeassistant/sensor/pisense_gas_resistance/config", gasPayload.c_str(), true);
}

// Send real sensor data
void sendSensorData() {
  String payload = "{";
  payload += "\"temperature\":";
  payload += bme.temperature;
  payload += ",\"humidity\":";
  payload += bme.humidity;
  payload += ",\"pressure\":";
  payload += bme.pressure / 100.0;
  payload += ",\"gas\":";
  payload += bme.gas_resistance / 1000.0;
  payload += "}";

  client.publish("home/pisense/bme680", payload.c_str(), true);
  Serial.println("Published data to MQTT: ");
  Serial.println(payload);
}


void setup() {
  // initialize digital pin LED_BUILTIN as an output.
  pinMode(LED_BUILTIN, OUTPUT);
  digitalWrite(LED_BUILTIN, HIGH);

  Serial.begin(115200);
  while (!Serial);
  setup_wifi();
  client.setServer(mqtt_server, 1883);
  client.setCallback(callback);

  Serial.println(F("BME680 async test"));

  if (!bme.begin(0x76)) { // If 0x77 does not work, try 0x76
    Serial.println(F("Could not find a valid BME680 sensor, check wiring!"));
    blinkError(3); // Blink 3 times to show there is an error
    while (1);
  }

  // Once connected, send MQTT discovery payload
  if (client.connected()) {
    sendDiscoveryPayloads();
    client.publish("home/pisense/status", "online", true);
  }

  Serial.println("BME680 detected!");

  // Oversampling and filter initialization
  bme.setTemperatureOversampling(BME680_OS_8X);
  bme.setHumidityOversampling(BME680_OS_2X);
  bme.setPressureOversampling(BME680_OS_4X);
  bme.setIIRFilterSize(BME680_FILTER_SIZE_3);
  bme.setGasHeater(320, 150); // 320*C for 150 ms
}

void loop() {
  checkWiFi();
  if (!client.connected()) {
    reconnect();
  }

  // Regularly call to maintain MQTT connection
  client.loop();

  // Chrono to perform new measure
  unsigned long currentTime = millis();
  if (currentTime - lastStatusUpdateTime >= statusUpdateInterval) {
    lastStatusUpdateTime = currentTime;
    client.publish("home/pisense/status", "online", true);
  }
  if (firstRunOrReconnect || currentTime - lastMeasurementTime >= measurementInterval) {
    if(firstRunOrReconnect){
      firstRunOrReconnect = false; // Deactivate special condition
      Serial.print("First run or recently reconnected - ");
    }
    Serial.println("Starting measurement...");
    lastMeasurementTime = currentTime; // Reinit the chrono

    digitalWrite(LED_BUILTIN, HIGH);

    // Begin BME680 measurement
    unsigned long endTime = bme.beginReading();
    if (endTime == 0) {
      Serial.println(F("Failed to begin reading... Check sensor connection."));
      blinkError(3); // Blink 3 times to show there is an error
      return;
    }

    // Blink during process
    unsigned long startTime = millis();
    while (millis() < endTime) {
      if (millis() - previousBlinkTimeMeasurement >= 100) {
        previousBlinkTimeMeasurement = millis();
        blinkMeasurementState = !blinkMeasurementState;
        digitalWrite(LED_BUILTIN, blinkMeasurementState);
      }
    }

    // Obtain measurement results from BME680
    // Note that this operation isn't instantaneous even if milli() >= endTime due to I2C/SPI latency.
    if (!bme.endReading()) {
      Serial.println(F("Failed to fetch results from sensor..."));
      blinkError(3); // Blink 3 times to show there is an error
      return;
    }

    // Indicate success with a quick LED blink
    Serial.println("Measurement successful. Preparing to publish data...");
    digitalWrite(LED_BUILTIN, HIGH);
    delay(100);
    digitalWrite(LED_BUILTIN, LOW);

    sendSensorData();

    // Print data via serial port just in case
    Serial.print(F("Temp = "));
    Serial.print(bme.temperature);
    Serial.print(F(" *C - "));

    Serial.print(F("Humidity = "));
    Serial.print(bme.humidity);
    Serial.print(F(" % - "));

    Serial.print(F("Pressure = "));
    Serial.print(bme.pressure / 100.0);
    Serial.print(F(" hPa - "));

    Serial.print(F("Gas = "));
    Serial.print(bme.gas_resistance / 1000.0);
    Serial.println(F(" KOhms"));

    Serial.print(F("Approx. Altitude = "));
    Serial.print(bme.readAltitude(SEALEVELPRESSURE_HPA));
    Serial.println(F(" m"));

    Serial.println();
    digitalWrite(LED_BUILTIN, LOW); // turn the LED off by making the voltage LOW
  }
}

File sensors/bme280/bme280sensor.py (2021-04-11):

import time
import datetime
import digitalio
import board
import busio
import adafruit_bme280
import json
import requests
import sys
import logging
import logging.handlers
import argparse
import textwrap
try:
    import configparser
except:
    from six.moves import configparser

config = configparser.ConfigParser()
config.read('config.ini')

''' default variables values '''
default_api_url = config['default']['default_api_url']
sending_timeout = int(config['default']['sending_timeout']) # timeout used to wait a certain amount of time before returning the get/post of API
default_time = int(config['environment']['default_time'])
localhost_usage = config.getboolean('default', 'localhost_usage')
api_usage = config.getboolean('default', 'api_usage')
JSON_FILE = config['environment']['json_file']
# Variables for rich notification
EVENT_NAME = config['notification']['eventName']
KEY = config['notification']['key']
PISENSE_ALERT_NOTIFICATION = config['notification']['pisense_alert_notification']
LOW_TEMPERATURE_CHECKUP = config.getfloat('environment', 'low_temperature')
HIGH_TEMPERATURE_CHECKUP = config.getfloat('environment', 'high_temperature')

''' arguments available to launch the app in a specific way '''
feature = argparse.ArgumentParser(prog='PiSense BME280', add_help=True, prefix_chars='-', allow_abbrev=True, formatter_class=argparse.RawTextHelpFormatter, description=textwrap.dedent('''\
        PiSense - BME280 module
        -----------------------
        This script is meant to be used with the Adafruit BMP280 sensor.
        Environmental values will be taken and sent throughout an API or directly written in a localhost website.
        The environmental values are: temperature, humidity and atmospheric pressure.
    '''))
feature.add_argument('-u', '--url', help='URL of the API', type=str, default=default_api_url, required=False)
feature.add_argument('-t', '--time', help='Time, in seconds, between each record taken', type=int, default=default_time, required=False)
feature.add_argument('-a', '--api', help='Sets API usage in activated state. Use this if you want to use API version (localhost will still run)', action='store_true', default=api_usage, required=False)
feature.add_argument('-v', '--version', help='%(prog)s program version', action='version', version='%(prog)s v0.9.1')
args = feature.parse_args()

''' Log configuration '''
logger = logging.getLogger('bme280')
logger.setLevel(logging.INFO)
LOG_ROTATE = 'midnight'
# create a file handler and timed rotating
handler = logging.handlers.TimedRotatingFileHandler('bme280.log', when=LOG_ROTATE, backupCount=7, utc=False) # 7 days backup
handler.setLevel(logging.INFO)
# create a logging format
formatter = logging.Formatter('%(asctime)s - %(name)s - %(levelname)s - %(message)s', '%Y-%m-%d %H:%M:%S')
handler.setFormatter(formatter)
# add the handlers to the logger
logger.addHandler(handler)
alice = logging.StreamHandler()
alice.setFormatter(formatter)
logger.addHandler(alice)

''' Create library object using Bus I2C or SPI port '''
# Create library object using Bus I2C port
#i2c = busio.I2C(board.SCL, board.SDA)
#bme280 = adafruit_bme280.Adafruit_BME280_I2C(i2c)

# Create library object using Bus SPI port
spi = busio.SPI(board.SCK, board.MOSI, board.MISO)
bme_cs = digitalio.DigitalInOut(board.D5)
bme280 = adafruit_bme280.Adafruit_BME280_SPI(spi, bme_cs)

bme280.sea_level_pressure = 1013.25 # Change this to match the location's pressure (hPa) at sea level
bme280.mode = adafruit_bme280.MODE_NORMAL
bme280.standby_period = adafruit_bme280.STANDBY_TC_500
bme280.iir_filter = adafruit_bme280.IIR_FILTER_X16
bme280.overscan_pressure = adafruit_bme280.OVERSCAN_X16
bme280.overscan_humidity = adafruit_bme280.OVERSCAN_X1
bme280.overscan_temperature = adafruit_bme280.OVERSCAN_X2

''' Clear terminal and welcome process before starting everything '''
print(chr(27) + "[2J")
print('Welcome to PiSense')
print('==================')
print('Altitude is calculated based on pressure information.')
logger.info('Start record of BME280 sensor')
logger.info('Altitude will not be shown nor used.')
print('-------------------')

if args.api:
    api_usage = True;
    logger.info('User asked to use API!')
else:
    api_usage = False;
    logger.info('Running localhost only version')

if args.url:
    default_api_url = args.url
    logger.info('API URL set up: %s', args.url)

if args.time:
    default_time = args.time
    logger.info('Time between records set up: %s seconds', args.time)

print('-------------------')

# The sensor will need a moment to gather initial readings
time.sleep(2)

''' Method which may be used to check if parameter used has a value that can be considered as boolean '''
def str2bool(v):
    if isinstance(v, bool):
        return v
    if v.lower() in ('yes', 'true', 't', 'y', '1'):
        return True
    elif v.lower() in ('no', 'false', 'f', 'n', '0'):
        return False
    else:
        raise argparse.ArgumentTypeError('Boolean value expected.')

''' ISO8601 format date and time'''
def get_date_time():
    return now.replace(tzinfo=datetime.timezone(offset=utc_offset)).isoformat()

''' JSON part '''
## {"datetime": "2019-11-14T10:11:59.378308+01:00", "temperature": 22.6, "humidity": 37.3, "pressure": 986.74}
def sensor_to_json():
    # dict which will be used by JSON
    # - 1°C hardcoded because digital calibration has 1°C higher value than reality
    bob = {'datetime': get_date_time(), # date T time in ISO8601
            'temperature': float(f'{bme280.temperature:.1f}') - 1, # in Celsius
            'humidity': float(f'{bme280.humidity:.1f}'), # in percentage
            'pressure': float(f'{bme280.pressure:.2f}')} # in hectopascal
    #date_json=bob
    # This part is for debug mode only because when used, it stop the sending of JSON to API
    # data_json = json.dumps(bob)
    logger.info('Records: %s', bob)

    # write JSON formatted data into specific file
    # with open('bme280data.json', 'a') as f:
    #    f.write(data_json + "\n")
    return bob

''' Fail method '''
def fail(msg):
    print(">>> Oops:",msg,file=sys.stderr)
    logger.warning('Oops: %s', msg)
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

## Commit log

2019-12-10 Add Blinka Test
    Blinka Test check if Digital IO, I2C and SPI are enabled and ready to use.
2019-12-22 Add Pimoroni fan SHIM
2020-01-04 First stage of BME280 sensor code
    Jumped version to v0.5
    - BME280 sensor data read
    - Everything is logged + rotation + auto-deletion when older than 30 days
    - Launch arguments available with included help menu (when called)
    - First idea of implementation if need of communication via API*
    - Launcher created + Update firstrun to match the launcher
    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
2020-01-08 Changed background of the webpage
    Change background from a gradient color to a picture taken myself.
    Picture shot at Serres Royales de Laeken (Brussels, Belgium) on October 5th, 2018.
2020-01-30 First stage of BME680 sensor code
    - BME680 sensor data read
    *API needs to be implemented
    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
2020-01-30 First stage of BMP280 sensor code
    - BMP280 sensor data read
    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
2020-02-05 Pinout diagram for sensors template
    Adobe Photoshop file
2020-02-20 First stage of NGINX Docker
2020-03-28 Switch to Flask Template
2020-03-28 First stage with DB
2020-04-02 First stage for API
    ImportError: cannot import name 'app' from partially initialized module 'pisenseapp.views' (most likely due to a circular import) (D:\Git\tfe-PiSense\web\www\pisenseapp\views.py)
2020-04-03 Second stage for API
    NameError: name 'User' is not defined
    Surely same problem about 'Box'
2020-04-13 Beginning of platform webpage
    Fully static webpage currently.
    Need to finish API before actually beginning the authentication part + graphs
2020-04-14 API: add_user now working
    add_user now working great.
    * Verificatrion if user already present in database (mail or name + firstname verification)
    * SensorsEnum now okay with request
    * Specified response + status code
2020-04-19 First stage for working register and connection form
    werkzeug.exceptions.BadRequestKeyError:
    400 Bad Request: The browser (or proxy) sent a request that this server could not understand.
    KeyError: 'mail'
2020-05-10 Add 3D box shaders for print + models used to check measures
    [BME680 Sensor Mount Pillars.stl, Nova PM SDS011 Sensor (simplified).stl, PiSense-box.stl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]
2020-05-20 First try with API
    This error occurs with BMP280, BME280, BME680.
    Need to continue to change SDS011 sensor code also in order to send data over API when all this will be fixed.
    Traceback (most recent call last):
    File "bme280/bme280sensor.py", line 121, in <module>
    post_data()
    File "bme280/bme280sensor.py", line 99, in post_data
    logger.info('Status code: %s - %s', str(r.status_code), r.json()['message'])
    File "/usr/lib/python3/dist-packages/requests/models.py", line 897, in json
    return complexjson.loads(self.text, **kwargs)
    File "/usr/lib/python3/dist-packages/simplejson/__init__.py", line 518, in loads
    return _default_decoder.decode(s)
    File "/usr/lib/python3/dist-p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
    [bme280sensor.py, bmp280sensor.py]
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2020-05-27 Fix wrong key-values for PM2.5 and PM10 in SDS011 sensor script
    Now API interpret correctly received data from SDS011 Python script
    [sds011sensor.py]
2020-05-31 Update s74 (API + database server)
    This server uses PHP with Agile Toolkit.
    Used for communication between Raspberry Pi and database via API interaction thanks to ATK4 (= Agile Toolkit) framework.
2020-06-01 Add pictures of Raspberry Pi device and 3D box modelisation
2020-06-02 Update NGINX security + switched to Cloudflare DNS resolver
2020-06-02 Switch API URL to HTTPS on each sensor script
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2020-06-09 Switched TLS protocols to v1.3 and v1.2 support only
    New SSL Labs report: grade A+
    Old SSL Labs report: grade B
2020-06-16 Defense final PowerPoint + last changes after 4 june and before defense of graduation work
2020-10-13 First stage of localhost web
    Localhost website which will be on the Raspberry Pi device and run under
    Lighttpd
2020-10-14 First stage to integrate environment values other than AQI
    By environment values, it's: temperature, humidity and pressure.
    I'm thinking about possibly add gas but still need to check a bit more about this specific value taken from Bosch BME680...
2020-10-16 BME680 sensor now writing in localhost (API temporarily deactivated)
2020-10-18 All sensors now writing in localhost (API temporarily deactivated)
    Sensors bumped to v0.7 to match all edits made on BME680.
    BME680 now will have gas values directly from the first recordings, normally.
    I need to check what is causing the API flag to not work properly.
    While checking that, API usage temporarily deactivated to prevent errors.
    [bme280sensor.py, bmp280sensor.py, sds011sensor.py]
2020-10-19 All sensors now working with localhost or API + localhost
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2020-10-26 localhost fix on sds011 sensor + fix on localhost web script
    [sds011sensor.py]
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2020-11-18 BMP280/BME280/BME680 fix config.ini calls + low/high temperature notification
    [bme280sensor.py, bmp280sensor.py]
2020-11-19 Fixed WAQI button for better UI
2020-12-14 Fix PM name in toast notification
    [sds011sensor.py]
2021-01-06 Fix wrong checkup of AQI used to send IFTTT notification
    A wrong checklist manage to send the smallest danger case even though an other one had to be sent.
    Example: "unhealthy for sensitive groups" in stead of "very unhealthy".
    [sds011sensor.py]
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2021-01-11 SDS011 sensor - code optimisation related to notification #1
2021-01-11 SDS011 sensor - code optimisation related to notification #2
2021-04-06 Terminal launcher for BME680 & SDS011 (Pi with GUI+Konsole)
    Small script launching Konsole on a Raspberry Pi device which has graphical interface activated.
    Automated 2 tabs with one on BME680, other on SDS011.
    Tabs are hold so that log info are visible.
2021-04-11 Fix temperature digital calibration BMP280/BME280/BME680
    All 3 sensors are calibrated and show a fixed higher temperature value of 1°C in comparison to reality.
    It's now hardcoded in order to match real values now.
    [bme280sensor.py, bmp280sensor.py]
2021-05-11 Bump Chart.js v2.9.3 to v3.2.1
    Patch done based on security alert CVE-2020-7746
    Prototype pollution in chart.js - https://github.com/advisories/GHSA-h68q-55jf-x68w
    This affects the package chart.js before 2.9.4. The options parameter is not properly sanitized when it is processed. When the options are processed, the existing options (or the defaults options) ar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
2021-05-13 Change fanshim scripts with preempt
    - Threshold on max temperature 65°C in stead of 60°C
    - Preempt flag: preemptively kick in the fan when CPU frequency raised
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2021-07-23 Switch from custom licensing to GNU GPL v3.0
    This project is by now on protected under GNU General Public License v3.0.
    It's made available on GitHub for "documentation" purpose. If you want to distribute it and/or use it commercially, please reach me before doing anything, thanks.
2022-11-26 Fix last clone in all sensors first run script
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2024-11-16 Add pinout diagram for RPi Pico with BME680
2024-11-20 First stage of Arduino code development
    Code is normally functional but I need to troubleshoot the MQTT
    connection because in my personal configuration, more security is needed
    (SSL/TLS and use of certificates)
2024-11-20 Switch delay to millis and changed serial print in end of loop
2024-11-24 Code is now successfully sending to MQTT broker but sensors are still not appearing on Home Assistant
    [ArduinoCode_RpiPico-BME680.ino]
2026-01-25 Add wiring circuit scheme and 3D model box
    [PiSense Lite box.stl]
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
